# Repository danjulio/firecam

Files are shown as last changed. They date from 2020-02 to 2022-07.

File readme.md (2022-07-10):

## FireCAM - Timelapse thermal imaging camera

FireCAM is a timelapse camera designed to take both visual and radiometric thermal images periodically and record them as json-structured files to a local Micro-SD Card.  The visual images are stored in jpeg format.  The thermal images are the raw radiometric data (temperature) to enable later analysis.  The camera includes a touch LCD control panel and a WiFi interface allowing control, configuration and grabbing of images from an external application.

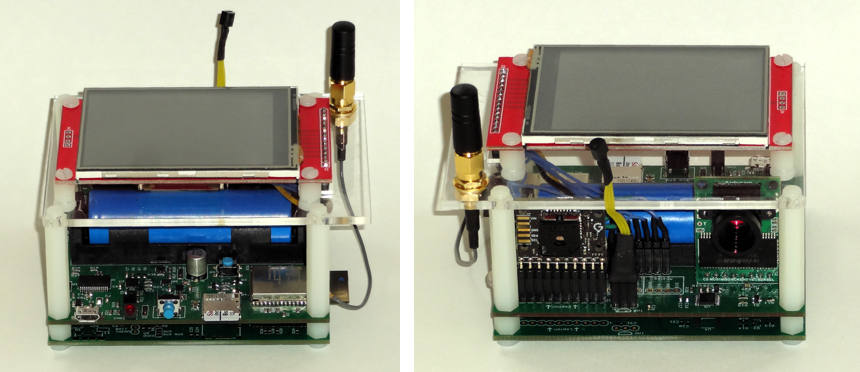
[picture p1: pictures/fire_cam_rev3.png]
FireCAM Rev 3 Hardware


### Features
* 160 x 120 pixel Radiometric Thermal Imaging Camera.
* 640 x 480 pixel Visual Imaging Camera.
* 2.8" 320 x 240 pixel Touchscreen for local control and configuration.
* Temperature sensor for external Thermal Imaging lens temp measurements.
* Micro-SD Card for image storage.
* Configurable timelapse times from 1 second to 1 hour per image.
* USB interface for charging, firmware updates and diagnostic output.
* 2500 mA LiPo battery with built-in charger can provide up to 5-6 hours of run-time and automatic low-battery shutdown.  Charger includes battery temperature monitor for charge limiting in extreme conditions.
* Wifi - AP or Client modes - for remote access.
* Battery-backed RTC for time and parameter storage.

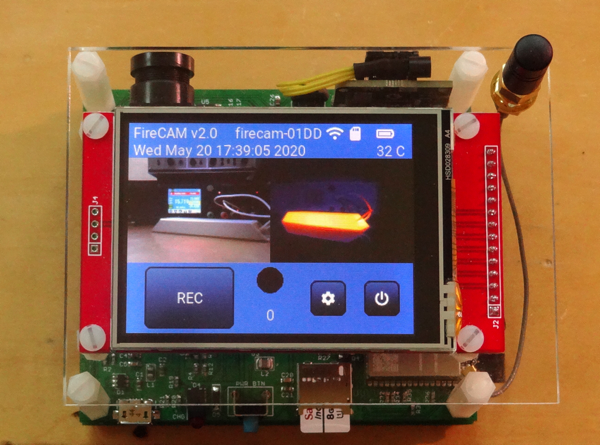
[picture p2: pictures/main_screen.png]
FireCAM Touchscreen Interface


### Origin
FireCAM was designed for the Joe O'Brien at [U.S. Forest Service Southern Research Station](https://www.srs.fs.usda.gov/).  It is released as Open Source software and hardware under the GPLv3 license.  The hardware design, firmware and a simple control application are contained in this repository.

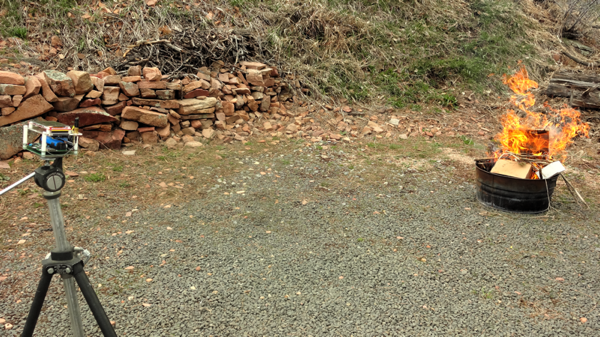
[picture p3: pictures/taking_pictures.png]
FireCAM in action


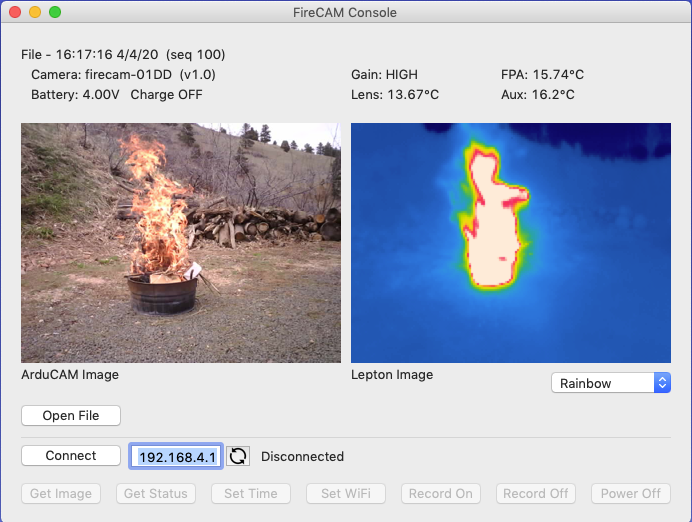
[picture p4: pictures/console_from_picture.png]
FireCAM Application


### Block Diagram
FireCAM 's image system is based around a FLiR Lepton 3.5 thermal imaging module and an ArduCAM visual sensor.  It uses an Espressif ESP32 micro-controller.  Firmware is written in C using the Esspressif v3.3.2 IDF and the LittlevGL v6.1.1 GUI library.  The desktop application is written using the Xojo cross-platform development tool.

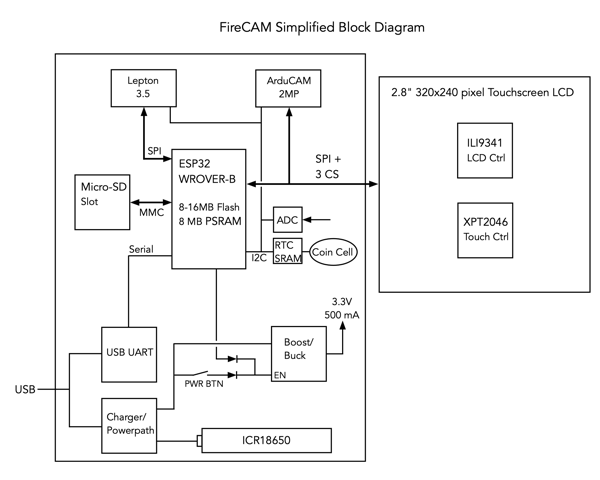
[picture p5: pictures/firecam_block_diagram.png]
FireCAM Block Diagram


### Version
This repository currently contains:

* Hardware Design Version: 3
* Firmware Revision: 2.1
* FireCAM Application Revision: 2.0

#### FW Revsion 2.1 Notes

1. Compile with QIO Flash access enabled (faster flash access).
2. Added Lepton state check (and refresh) before each acquisition.
3. Fixed minor bug in lepton init code (no functional impact).
4. Increased GUI task execution to every 50 mSec (was 100 mSec).
5. Additional performance debugging capabilty (disabled by default).

### Digital Object Identifier


### Questions
FireCAM was designed by Dan Julio (dan@danjuliodesigns.com).  Units may be available for purchase for qualified customers.  Customizations of the hardware, firmware or application are possible.

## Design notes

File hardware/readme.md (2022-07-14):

## FireCAM Hardware
This directory contains hardware design files.  Schematic entry and PCB layout was done using Eagle 7.7.

* display_mount - DXF and SVG files for a laser cut plastic display mount, OpenSCAD and STL files for a 3-piece 3D printed base and display mount.
* documentation - BOM, schematic, PCB image and helpful list of componentst to load on the PCB.
* eagle - Schematic and PCB Layout design files.
* gerber - PCB gerber files
* stencil - Stencil gerber files

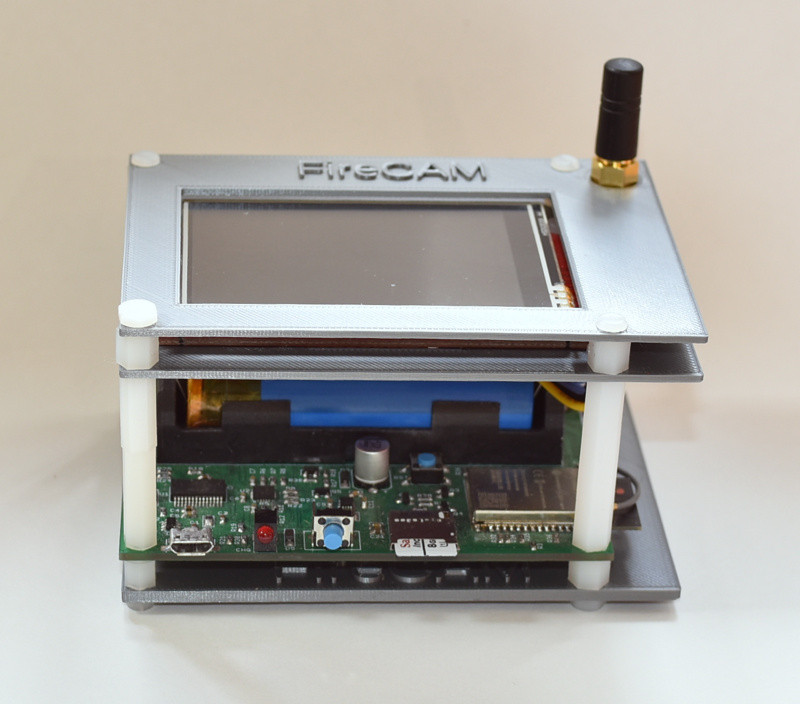
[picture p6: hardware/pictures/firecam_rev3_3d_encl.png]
FireCAM unit 3D enclosure

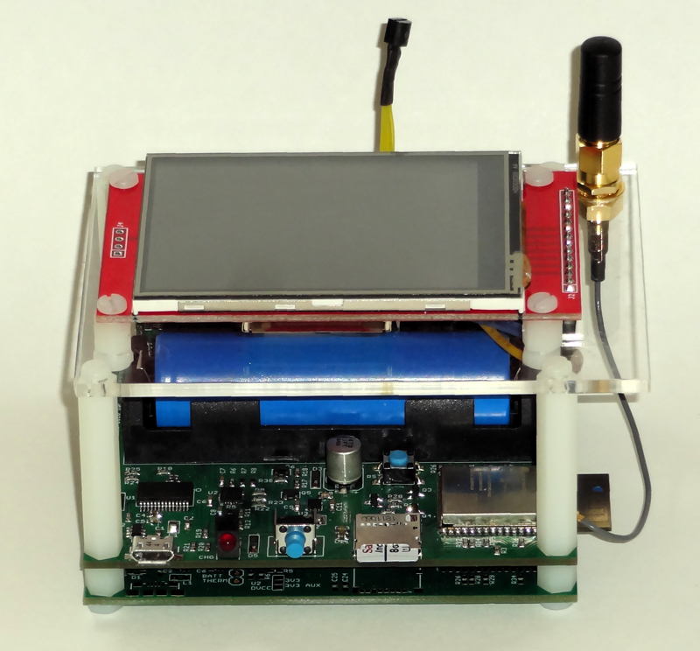
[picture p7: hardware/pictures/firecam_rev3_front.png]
FireCAM unit front


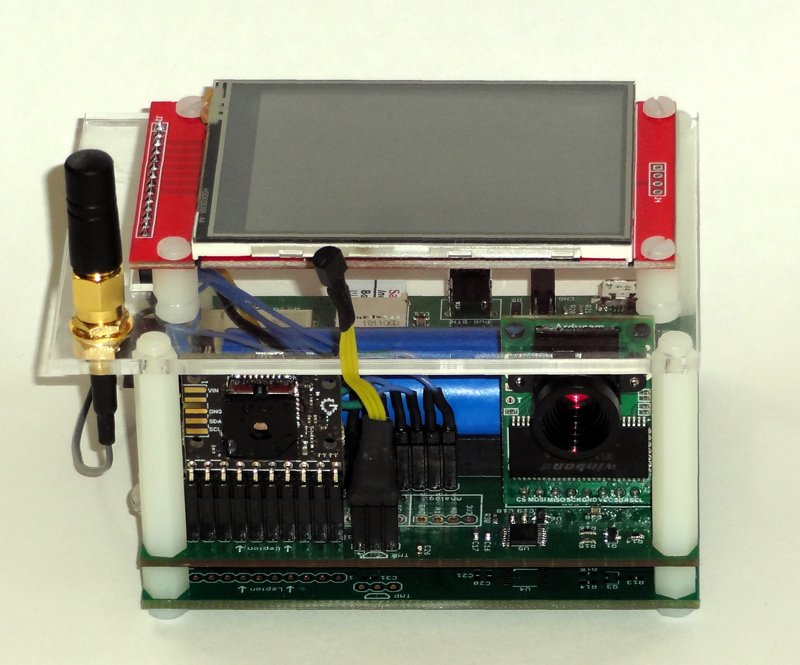
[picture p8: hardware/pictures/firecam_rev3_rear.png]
FireCAM unit rear


### Parts
Two shared Mouser BOMs are available for most of the components.

1. [FireCAM Rev 3 PCB Parts](https://www.mouser.com/ProjectManager/ProjectDetail.aspx?AccessID=e3b4e6fe5d) - Parts for direct mounting on the PCB.
2. [FireCAM Rev 3 Assembly Parts](https://www.mouser.com/ProjectManager/ProjectDetail.aspx?AccessID=ba0938d0f0) - Additional assembly parts.

In addition a commonly available 2.8" ILI9341/XPT2046 LCD display is used.  I have successfully sourced many units from the [HiLetGo](https://www.amazon.com/HiLetgo-240X320-Resolution-Display-ILI9341/dp/B073R7BH1B) store on Amazon but they are available from many sources.  You will also need some flexible 28 AWG silicon hook-up wire and heat shrink to make the Temperature Sensor and LCD wiring harnesses and a Micro-SD Card.

### Main PCB
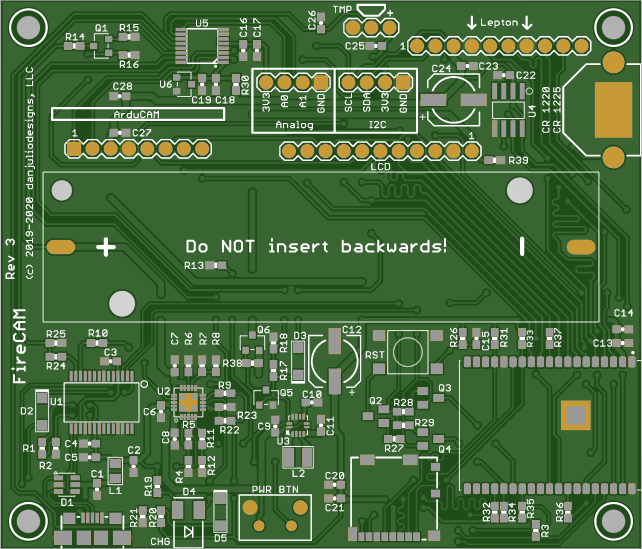
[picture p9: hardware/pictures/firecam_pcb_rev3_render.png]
FireCAM Rev 3 PCB Image


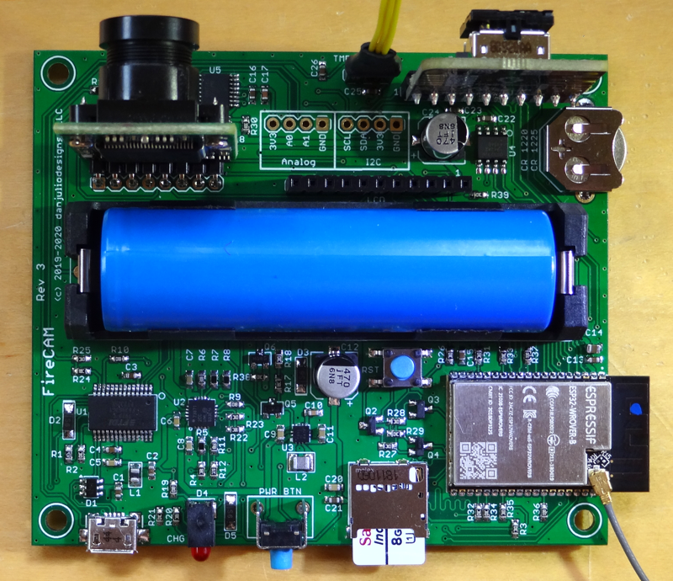
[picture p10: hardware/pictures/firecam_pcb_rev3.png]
FireCAM Rev 3 PCB


### Subassemblies

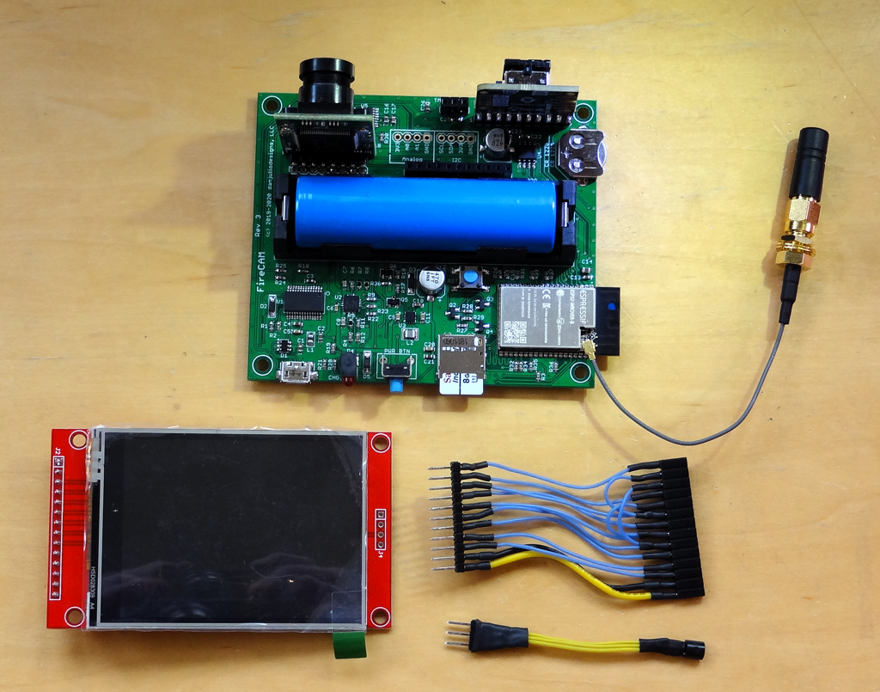
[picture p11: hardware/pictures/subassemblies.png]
FireCAM Subassemblies


#### Temperature probe
The TMP36 temperature sensor is connected to a 3-pin male 0.1" (2.54mm) using 3 2" (51 mm) 28 AWG wires.  Heatshrink each individual connection and the wire assembly to each of the connector and temperature sensor.  Note the orientation of the sensor relative to the connections on the PCB.

#### Display wiring harness
The Display harness contains the shared SPI bus for the LCD and Touchscreen, control, and power signals.  The shared SPI bus signals are connected at the display side in order to minimize signal reflections.
 
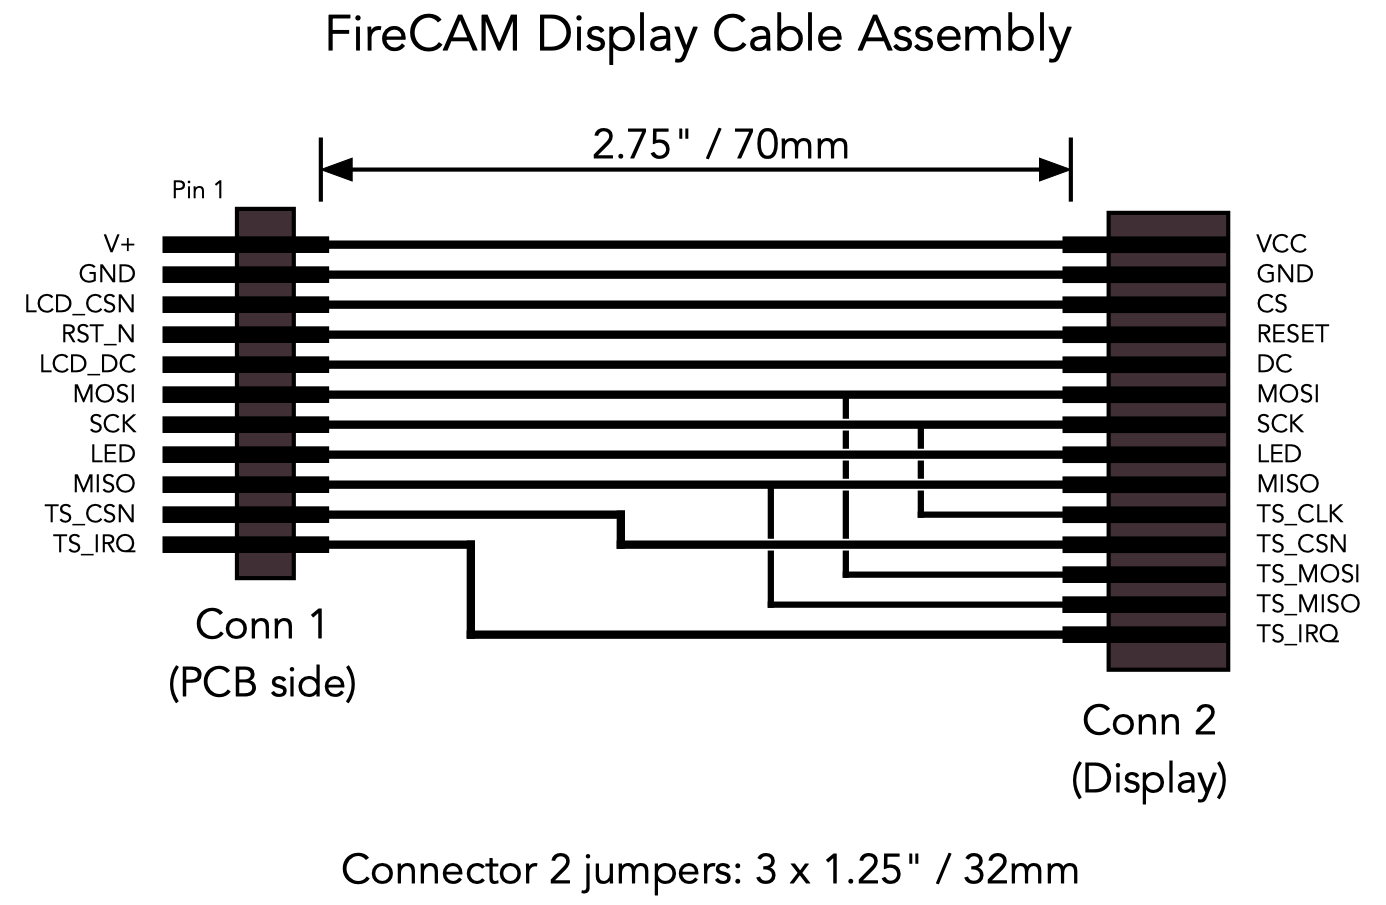
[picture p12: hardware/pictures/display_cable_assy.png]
FireCAM Display Wiring Harness


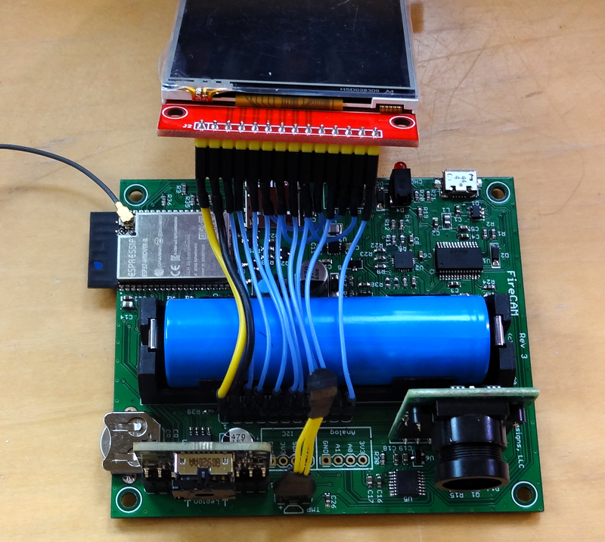
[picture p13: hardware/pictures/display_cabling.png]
FireCAM Wiring Harness Detail


#### 3D Printed Base and Display Mount
A base and two-piece display mount may be printed by slicing the STL files for your particular printer.  The STL was generated using OpenSCAD and the source files included here.

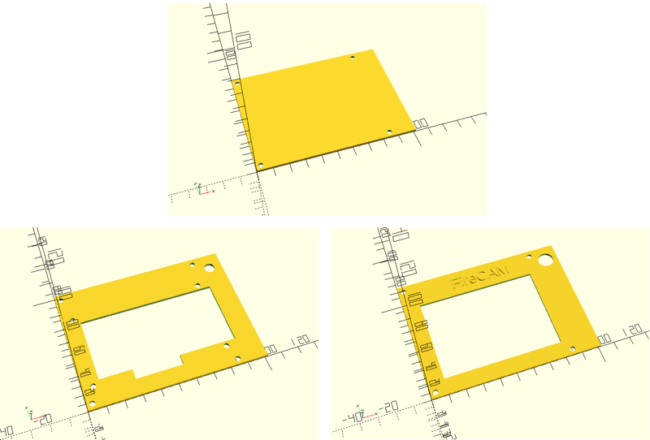
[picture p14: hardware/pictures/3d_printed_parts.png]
FireCAM 3D Printed Mount


#### Laser Cut Display Mount
The display mount is designed to be cut from a piece of 1/8" plastic on a laser cutter.

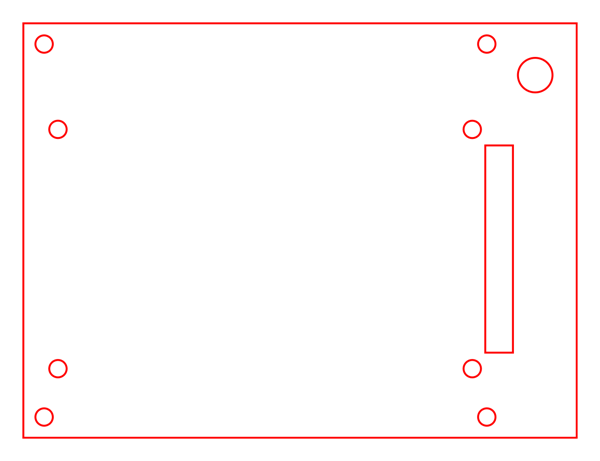
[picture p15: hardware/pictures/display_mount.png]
FireCAM Display Mount


### Enclosure
FireCAM is released without an enclosure as the original client for the project built their own custom enclosure for it.

### Expansion Ports

1. I2C Bus
2. ADC inputs A0 and A1 (not currently used by the firmware)

### Important Notes

1. Do not insert the LiPo battery backwards!  This will damage the camera electronics.
2. The RTC has a higher-than normal draw from the coin cell until it has been initialized.  Load firmware before inserting the coin cell and then immediately power on the camera to initialize the RTC (even if it has the wrong time).
3. Do not enable WiFi unless the antenna is connected.  It is possible to damage the ESP32 without an antenna.
4. The camera is charged from the USB port.  It will take a maximum of 500 mA from this port if it detects a charger attached (D+ connected to D-) or the USB port has been enumerated by an attached computer.  It will take a maximum of 100 mA from this port when attached to a computer but not enumerated.  It will suspect power draw when the USB bus is suspended (e.g. computer is put to sleep).  Current is shared between charging the battery and power the camera so the battery will charge faster if the camera is powered off.  The red LED lights while charging.  It will not charge if D+/D- are not connected together or connected to a computer USB port.  Most USB chargers will work.

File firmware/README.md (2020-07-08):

## FireCAM Firmware
This directory contains the firmware source files, build support and pre-compiled binary files ready for programming into hardware using EspressIF tools.

Firmware is written in C using the EspressIF v3.3.2 IDF (which must be installed on your computer) and the LittlevGL v6.1.1 GUI library (included here).  The firwmare consists of several concurrently operating FreeRTOS tasks that communicate using notifications, shared buffers and mutex protected data structures.

* components - Support libraries and modules.
* main - Primary task modules.
* precompiled - Contains the pre-compiled binary files copied from the build directory (not included here).
* sdkconfig - IDF build configuration.  You will have to run this, at least, to set the USB Serial device for your camera.
* version.txt - Firmware version source file.

The EspressIF IDF documentation, including instructions for installing and building, can be found [here](https://docs.espressif.com/projects/esp-idf/en/v3.3.2/index.html).

### Local Control
Pressing the power button applies power to the camera.  It must be held until the firmware boots and sets a hold signal to keep power applied until it is ready to poweroff the camera (from a user action, remote command or low-battery condition).  This requries about 2-3 seconds.  The LCD backlight is switched on when the hold signal is asserted.

#### Main Screen

The camera's touch controls are fairly intuitive.  Functionality is split into several screens. The main screen is displayed after the camera boots. It displays an image updated once per second from both cameras, provides status information and controls to start/stop recording, enter the settings screens and power-off the camera.  The camera may also be powered off by pressing and holding the power button for more than two seconds.  A power-off screen is displayed when the camera powers down.

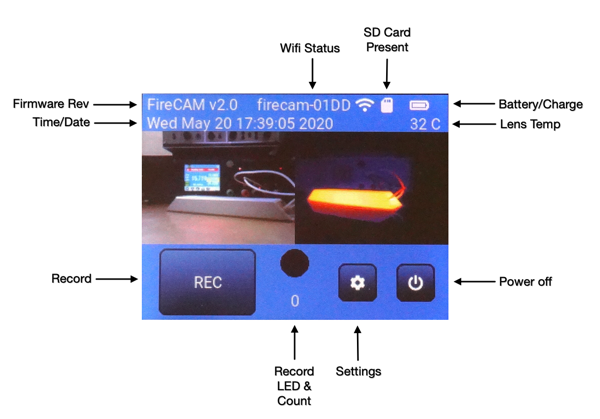
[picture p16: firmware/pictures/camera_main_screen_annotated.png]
Main Screen


* Battery/Charge - An estimate of the battery capacity is shown in the battery icon (0, 25, 50, 75, 100%) and a charge icon appears while the camera is charging the battery from the USB port.
* Firmware Rev - revision as contained in the version.txt file.
* Lens Temp - Temperature of the external TMP36 sensor.
* Power Button - Immediately powers down the camera.
* Record Button - Starts and stops recording.
* Record LED and Count - A simulated red LED is lit while recording and the number of images recorded during this session is displayed below it.
* SD Card Present - An icon shows when a Micro-SD Card has been inserted into the camera and recording can be started.  A pop-up messagebox is displayed if recording is attempted without an installed card.
* Settings Button - Displays the camera main settings screen.
* Time/Date - Displays the current time and date maintained by the camera.  This information is used to construct a unique directory for each recording session.
* WiFi Status - The current selected SSID is displayed.  When the camera is configured as an Access Point this is also the camera name.  A WiFi icon is displayed when the WiFi is active.

By default each camera is named ```firecam-HHHH``` where the 4-character hex string `HHHH` are from the ESP32's unique SoftAP Mac address.

#### Main Settings Screen

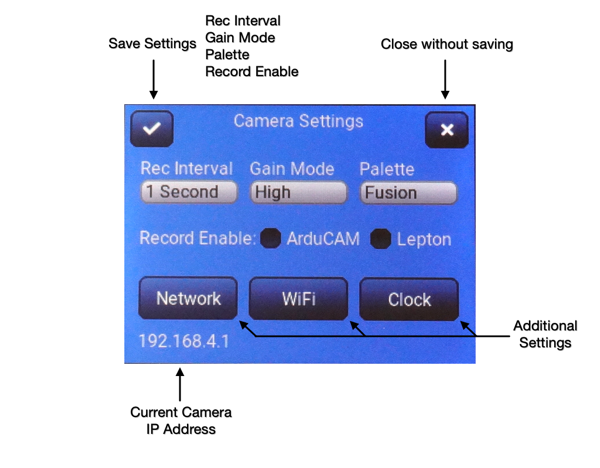
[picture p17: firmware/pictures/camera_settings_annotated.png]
Settings Screen


The main settings screen allows configuration of camera operating parameters.  The parameters, along with the time, are maintained by the battery-backed RTC chip when the camera is powered down.

* Additional Settings Buttons - These open additional settings screens.
* Close Without Saving Button - Returns to the main screen and discards any changes made to the Recording Interval, Gain Mode, Palette or Record Enable.
* Current Camera IP Address - Displays the Camera's IP address when it is acting as an Access Point.  Displays the Camera's IP address (either DHCP or static) when it is a client and connected to another Access Point.
* Save Settings - Save the values displayed for the Recording Interval, Gain Mode, Palette and Record Enable.

Camera Parameters modifed by this screen include the following.

* Rec Interval - Configures the time between recorded images when the camera is recording.   These values range from 1 second to 1 hour.
* Gain Mode - Configure the Lepton Gain Mode (please refer to the Lepton documentation for a detailed descripton of Gain Mode).
* Palette - Configures the false color palette used to display images from the Lepton on the main screen.
* Record Enable - Allows control of what camera images are saved during recording.  This may be useful, for example, to disable the ArduCAM when taking timelapse images at night.  One or both cameras must be selected.

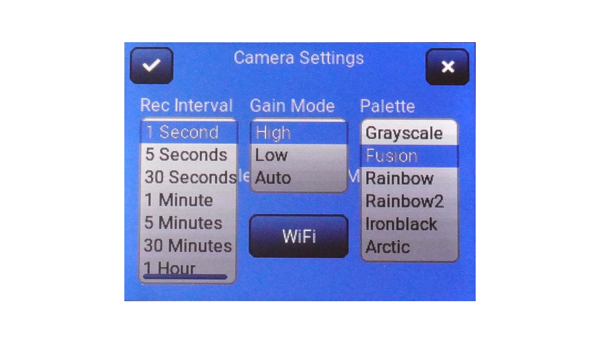
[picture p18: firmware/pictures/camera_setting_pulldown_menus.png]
Setting Screen Selections


#### Clock Settings Screen

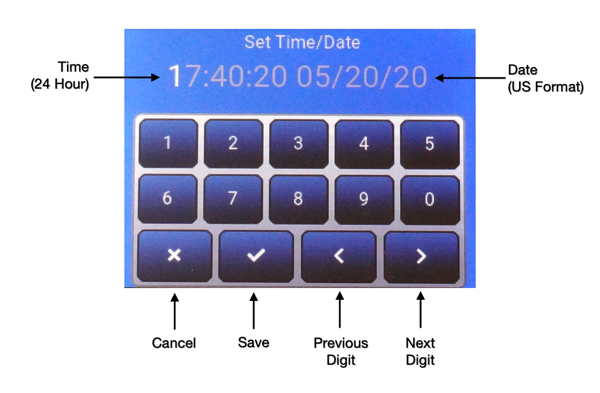
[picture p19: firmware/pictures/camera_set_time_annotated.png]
Clock Settings Screen


The Clock settings screen allows setting the camera's time and date. The time and date are set by entering them from left to right using the numeric keypad.  The currently selected digit is highlighted and automatically moves to the next digit as numbers are entered.  The screen will not allow setting illegal times or dates.

* Cancel Button - Returns to the main settings screen without changing the time and date.
* Next Digit Button - skips ahead to the next digit.
* Previous Digit Button - backs up one digit.
* Save - Saves the currently displayed time and date to the camera and RTC chip then returns to the main settings screen.

#### Wifi Settings Screen

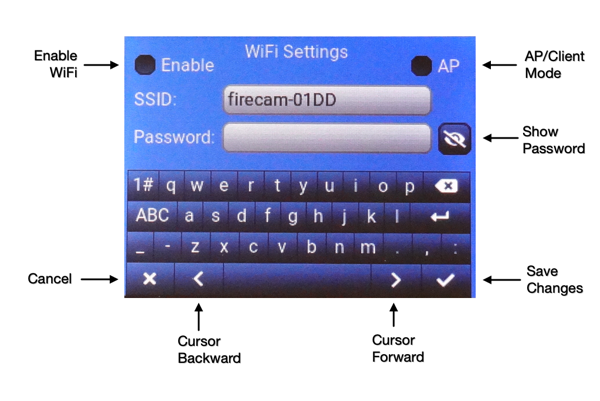
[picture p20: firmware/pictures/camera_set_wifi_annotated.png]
WiFi Settings Screen


The Wifi settings screen allows enabling or disabling WiFi, configuring the camera as an Access Point or client, and setting the camera's SSID and WPA password.  Note that it may be easier to use a stylus on the camera's resistive touch screen for entering information on this screen.

* AP/Client Mode Checkbox - Selecting this checkbox configures the camera as an Access Point that can support one client via DHCP.  De-selecting this checkbox configures the camera as a client that will attempt to connect to an Access Point.
* Cancel - Returns to the main settings screen without changing the WiFi configuration.
* Cursor Backward Button - Moves the cursor left one character position in the selected text box.
* Cursor Forward Button - Moves the cursor right one character position in the selected text box.
* Enable WiFi Checkbox - Selecting this checkbox enables the camera's WiFi interface.  De-selecting this checkbox disables the camera's WiFi interface.
* Password Text Box - Click in this to select it and enter up to a 32-character password.  When the camera is configured as an Access Point this is the password the connecting computer will use.  When the camera is configured as a client this is the password the camera will use.
* Save Changes Button - Saves the displayed WiFi configuration and returns to the main settings screen.  Restarts the WiFi as necessary with the new configuration.
* Show Password Button - Toggles showing or hiding the contents of the Password text box.
* SSID Text Box - Click in this to select it and enter up to a 32-character SSID.  When the camera is configured as an Access Point this is the SSID the camera will broadcast for the connecting computer to use.  When the camera is configured as a client this is the SSID the camera will attempt to connect with.

#### Network Settings Screen

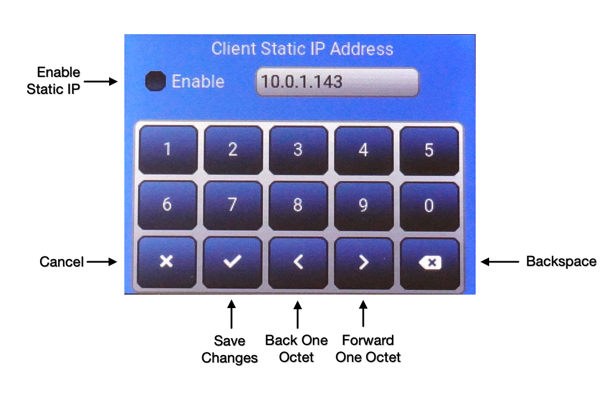
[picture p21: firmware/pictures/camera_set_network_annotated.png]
Network Settings Screen


The Network settings screen allows selecting between DHCP and Static IP addresses when the camera is configured as a client to another Access Point, and setting the static IP address.  A netmask of ```255.255.255.0``` is assumed by this version of the firmware.  The camera's current static IP address is displayed with a cursor at the end of the final octet.  Changes are made using the numeric keypad.  The screen will not allow creation of an illegal IP address.

* Backspace Button - Deletes the character immediately preceeding the cursor.  Sets the octet to 0 if the all characters in the octet are deleted.
* Back One Octet Button - Moves the cursor past the end character of the preceeding Octet value.
* Cancel Button - Returns to the main settings screen without changing the Network configuration.
* Enable Static IP Checkbox - Selecting this checkbox enables the camera to use a Static IP address.  De-selecting this checkbox enables the camera to request an address using DHCP.
* Forward One Octet Button - Moves the cursor past the end character of the subsequent Octet value.
* Save Changes Button - Saves the displayed Network configuration and returns to the main settings screen.  Restarts the WiFi as necessary with the new configuration.

### Recording Files
Recorded images are saved as json-structured files with several objects.  Each file is typically 70-100 kBytes in length.

* Metadata - Information about the camera and its environment.
* Visual Image - The variable length jpg image from the ArduCAM is formatted using Base-64.
* Lepton Radiometric Image - The 38,400 byte 16-bit per pixel radiometric (temperature) data from the Lepton is formatted using Base-64.
* Lepton Telemetry Data - The 480 byte 16-bit per word telemetry package containing information about the camera at the time the image was recorded is formatted using Base-64.

#### Missing Json objects
Occasionally one or both of the camera's may fail to generate an image.  The ArduCAM occasionally fails to generate a legal jpeg images (reason unknown).  The Lepton will not generate images while it is performing a flat-field correction.  If either or both of these occurs then the related object is not included in the file.

#### Recording Directory Layout
Files from one recording session are stored in two-level directory structure at the root of the Micro-SD card.  The top-level directory name is created from the current date and time.

```session_YY_MM_DD_HH_MM_SS```

Files are grouped in sets of 100 files per sub-directory under that.  Each sub-directory is named with an incrementing number starting at 0.  This is to mitigate performance issues with the underlying FAT-FS library as it scans a directory looking for duplicate file names.

```group_NNNN```

Files are named with an incrementing number starting at 0.

```img_MMMMM.json```

#### File Format
A complete file is shown below.  Most of the Base-64 data is omitted for clarity.

```
{
  "metadata": {
    "Camera": "firecam-01DD",
    "Version": "2.0",
    "Sequence Number": 0,
    "Time": "21:18:39",
    "Date": "5/18/20",
    "Battery": 4.170127868652344,
    "Charge": "OFF",
    "FPA Temp": 34.769981384277344,
    "AUX Temp": 34.969993591308594,
    "Lens Temp": 35.67091751098633,
    "Lepton Gain Mode": "HIGH",
    "Lepton Resolution": "0.01"
  },
  "jpeg": "/9j/4AAQSkZJRgABAQEAAAAAAA..."
  "radiometric": "I3Ypdg12B3YPdgt2BXYRdgF2A3YFdgF2AXYNdv91+3ULdvd..."
  "telemetry": "DgCDMSkAMAgAABBhCIKyzJpkj..."
}
```
Temperature values are in °C.  The sequence number is the same as the incrementing number in the file's name.  Battery value is in volts.

The Lepton Resolution is used with the Radiometric data to compute the temperature of each pixel.  The data is encoded either as °K with a resolution of 0.01°K (27315 = 0°C) or a resolution of 0.1°K (2731 = 0°C).

Refer to the Lepton 3.5 documentation for more information and for the contents of the telemetry object.

### Remote Command Interface
The camera is capable of executing a set of commands and providing a set of responses when connected to a remote computer via the WiFi interface.  It can support one remote connection at a time.  Commands and responses are encoded as json-structured strings.  The command interface exists as a TCP/IP socket at port 5001.

Each json command or response is delimited by two characters.  A start delimitor (value 0x02) preceeds the json string.  A end delimitor (value 0x03) follows the json string.  The json string may be tightly packed or may contain white space.  However no command may exceed 256 bytes in length.

```<0x02><json string><0x03>```

The camera currently supports the following commands.  The communicating application should wait for a response from commands that generate one before issuing subsequent commands (although the camera does have some buffering - 1024 bytes - for multiple commands).

* get_status - Returns an object with camera status.  The application uses this to verify communication with the camera.
* get_image - Returns an object, structured identically as the image file, with metadata, jpeg, radiometric and telemetry objects.  This command should be issued no more frequently than once per second and the application should wait for a response before issuing it again.
* set_time - Set the camera's clock and RTC.  Does not return anything.
* get_config - Returns an object with the camera's current settings.
* set_config - Set the camera's settings.  Does not return anything.
* get_wifi - Returns an object with the camera's current WiFi and Network configuration.
* set_wifi - Set the camera's WiFi and Network configuration.  The WiFi subsystem is immediately restarted.  The application should immediately close its socket after sending this command.  Does not return anything.
* record_on - Start a recording session.
* record_off - End a recording session.
* poweroff - Power down the camera.

The camera currently generates the following responses.

* config - Response to get_config command.
* image - Response to get_image command.
* status - Response to get_status command.
* wifi - Response to get_wifi command.

Example commands and responses are shown below.

#### get_status

```{"cmd":"get_status"}```

#### get_status response
```
{
  "status": {
    "Camera": "firecam-01DD",
    "Version": "2.0",
    "Recording": 0,
    "Time": "21:23:26",
    "Date": "5/18/20",
    "Battery": 4.170127868652344,
    "Charge": "OFF"
  }
}
```
The Recording object is set to 1 when the camera is recording and 0 when it is not.

#### get_image

```{"cmd":"get_image"}```

#### get_image response
The get_image response contains the exact same content as a file.  The Sequence Number will always contain the number 0 unless the camera is recording.

```
{
  "metadata": {
    "Camera": "firecam-01DD",
    "Version": "2.0",
    "Sequence Number": 0,
    "Time": "21:18:39",
    "Date": "5/18/20",
    "Battery": 4.170127868652344,
    "Charge": "OFF",
    "FPA Temp": 34.769981384277344,
    "AUX Temp": 34.969993591308594,
    "Lens Temp": 35.67091751098633,
    "Lepton Gain Mode": "HIGH",
    "Lepton Resolution": "0.01"
  },
  "jpeg": "/9j/4AAQSkZJRgABAQEAAAAAAA..."
  "radiometric": "I3Ypdg12B3YPdgt2BXYRdgF2A3YFdgF2AXYNdv91+3ULdvd..."
  "telemetry": "DgCDMSkAMAgAABBhCIKyzJpkj..."
}
```

### set_time

```
{
  "cmd": "set_time",
  "args": {
    "sec": 14,
    "min": 10,
    "hour": 21,
    "dow": 2,
    "day": 18,
    "mon": 5,
    "year": 50
  }
}
```
All set_time args must be included.

* sec - Seconds 0-59
* min - Minutes 0-59
* hour - Hour 0-23
* dow - Day of Week starting with Sunday 1-7
* day - Day of Month 1-28 to 1-31 depending
* mon - Month 1-12
* year - Year offset from 1970

#### get_config

```{"cmd":"get_config"}```

#### get_config response

```
{
  "config": {
    "arducam_enable": 1,
    "lepton_enable": 1,
    "gain_mode": 0,
    "record_interval": 1
  }
}
```
* arducam\_enable - Set to 1 to when the ArduCAM is enabled for recording sessions, set to 0 when it is disabled.
* lepton\_enable - Set to 1 to when the Lepton is enabled for recording sessions, set to 0 when it is disabled.
* gain\_mode - Set to 0 when the Lepton is configured in High Gain mode, set to 1 when the Lepton is configured in Low Gain mode and set to 2 when the Lepton is configured to automatically select between gain modes.
* record\_interval - Tthe number of seconds between recorded images in record mode.

#### set_config

```
{
  "cmd": "set_config",
  "args": {
    "arducam_enable": 1,
    "lepton_enable": 1,
    "gain_mode": 0,
    "record_interval": 1
  }
}
```
Individual args values may be left out.  The camera will use the existing value.

* arducam\_enable - Set to 1 to enable the ArduCAM during recording sessions, set to 0 to disable it.  At least one of arducam\_enable and lepton\_enable should be set.
* lepton\_enable - Set to 1 to enable the Lepton during recording sessions, set to 0 to disable it. At least one of arducam\_enable and lepton\_enable should be set.
* gain\_mode - Set to 0 to configure the Lepton in High Gain mode, set to 1 to configure the Lepton in Low Gain mode and set to 2 to configure the Lepton to automatically select between gain modes.
* record\_interval - Set the number of seconds between recorded images in record mode.  Note that this should match the firmware's existing values which are currently 1, 5, 30, 60, 300, 1800 or 3600.

#### get_wifi

```{"cmd":"get_wifi"}```

#### get_wifi response

```
{
  "wifi": {
    "ap_ssid": "firecam-01DD",
    "sta_ssid": "RoboNet",
    "flags": 159,
    "ap_ip_addr": "192.168.4.1",
    "sta_ip_addr": "10.0.1.144",
    "cur_ip_addr": "10.0.1.144"
  }
}
```
* ap_ssid - The camera's current AP-mode SSID and also the camera name as reported in the metadata and status objects.
* sta_ssid - The SSID used when the camera's WiFi is configured as a client.
* flags - 8-bit WiFi Status
	* 	Bit 7: Client Mode - Set to 1 for Client Mode, 0 for AP mode.
	* 	Bit 4: Static IP - Set to 1 to use a Static IP, 0 to request an IP via DHCP.
	* 	Bit 3: Wifi Connected - Set to 1 when connected to another device.
	* 	Bit 2: Wifi Client Running - Set to 1 when the client has been started, 0 when disabled (obviously this bit will never be 0).
	* 	Bit 1: Wifi Initialized - Set to 1 when the WiFi subsystem has been successfully initialized (obviously this bit will never be 0).
	* 	Bit 0: Wifi Enabled - Set to 1 to enable Wifi, 0 to disable Wifi.
* ap\_ip_addr - The camera's IP address when it is in AP mode (currently it will always be 192.168.4.1).
* sta\_ip_addr - The static IP address to use when the camera is in Client mode and configured to use a static IP.
* cur\_ip_addr - The camera's current IP address.  This may be a DHCP served address if the camera is configured in Client mode with static IP addresses disabled.

#### set_wifi
```
{
  "cmd": "set_wifi",
  "args": {
    "ap_ssid": "FireCam-3"
    "ap_pw: "apassword"
    "ap_ip_addr": "192.168.4.1",
    "flags": 145,
    "sta_ssid": "RoboNet",
    "sta_pw": "anotherpassword",
    "sta_ip_addr": "10.0.1.144"
  }
}
```
Individual args values may be left out (for example to just set AP or Client (sta) values.  The camera will use the existing value.

Only a subset of the flags argument are used.  Other bit positions are ignored.

* Bit 7: Client Mode - Set to 1 for Client Mode, 0 for AP mode.
* Bit 4: Static IP - Set to 1 to use a Static IP, 0 to request an IP via DHCP.
* Bit 0: Wifi Enabled - Set to 1 to enable Wifi, 0 to disable Wifi.

#### record_on

```{"cmd":"record_on"}```

#### record_off

```{"cmd":"record_off"}```

#### poweroff

```{"cmd":"poweroff"}```

### Special Notes
1. Recording resumes automatically if the firmware crashes.
2. Press and hold the power button when loading new firmware to keep the camera powered during the process (the hold signal from the ESP32 will be de-asserted when the ESP32 is reset before reprogramming).

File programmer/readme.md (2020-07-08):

## FireCAM Firmware Upload
There are two ways to load firmware into FireCAM.

1. Using the Espressif build process after compiling the firmware.
2. Using a download tool from Espressif to load the pre-compiled firmware from this repository.

The second option is described here.  It requires a Microsoft Windows computer.

### Download firmware files
Download the three binary files from this repository to a known location.  All three are required by the Espressif download tool.

```
	firmware/precompiled/bootloader.bin
	firmware/precompiled/firecam.bin
	firmware/precompiled/partitions_singleapp.bin
```

### Connect Camera
Connect the camera to the Windows Computer to allow it to load a device driver for the camera's FTDI USB-Serial chip.  The camera does not need to be powered on.  After a few minutes the computer should load a driver and associate a COM port with the camera.  Make a note of this port.  You can find it in the Windows Device Manager.

### Install the Espressif download tool
Download the `flash_download_tools_v3.6.8.zip` file to a Windows computer.  Unzip it in a known location.  It will unzip a directory named `flash_download_tools_v3.6.8`.  Execute the ```flash_download_tools_v3.6.8``` binary from within that directory.

A shell window will appear and then after a few seconds a selection window will appear.

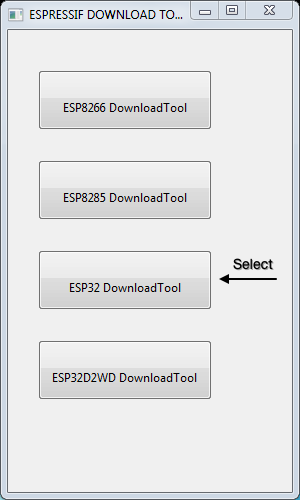
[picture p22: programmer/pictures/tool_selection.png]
Espressif Tool Selection


Click the `ESP32 Download Tool` button.  The ESP32 Download Tool program runs and displays a new window.

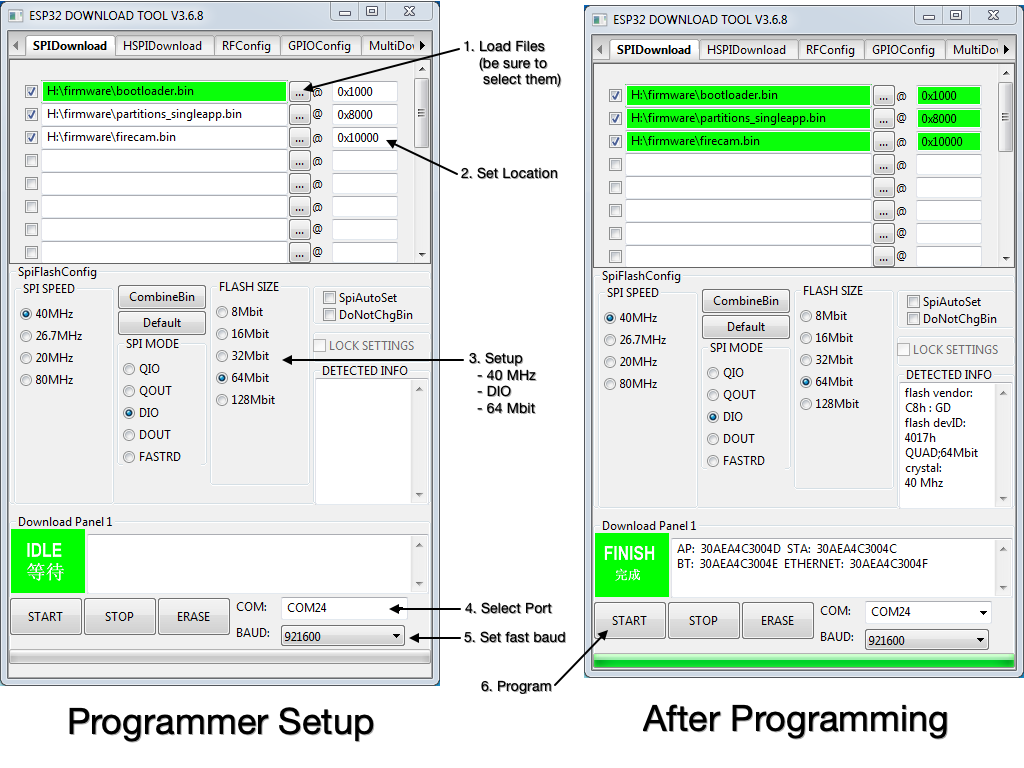
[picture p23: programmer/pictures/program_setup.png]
Espressif ESP32 Download Tool


#### Programmer Setup

1. Load the three firmware files from the location you stored them by clicking on first three `...` buttons as shown above under the `SPIDownload` tab.
2. Set the location in ESP32 memory for each file as shown above by clicking in the text fields to the right of each filename.
3. Configure the programming parameters in the `SpiFlashConfig` area.  Select SPI SPEED: 40 MHz, SPI MODE: DIO, FLASH SIZE: 64 Mbit.
4. Select the COM port associated with the camera.
5. Set a fast baud rate of 921600 baud to reduce programming time.

#### Programming

1. Press and hold the power button on the camera.  It will boot up but this does not matter (the programming software will reset it).
2. Continue to hold the power button depressed and press `START` to initiate programming.  A green progress bar will progress along the bottom of the window.  Programming should take 15-20 seconds.  The program will display `FINISH` upon a successful programming.
3. Release the power button and then press it again.  The camera should boot into the new firmware.

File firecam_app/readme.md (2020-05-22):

## FireCAM Application Program
This directory contains the FireCAM application program, compiled as 64-bit binaries for Windows and OS X platforms and its source code written for the Xojo development environment.

The Application program provides two functions.

1. Remote Camera Control - Get status and control the camera remotely including the ability to view live images from the camera.
2. Simple File Viewing - View files that have been copied from the camera's Micro-SD card to the computer.

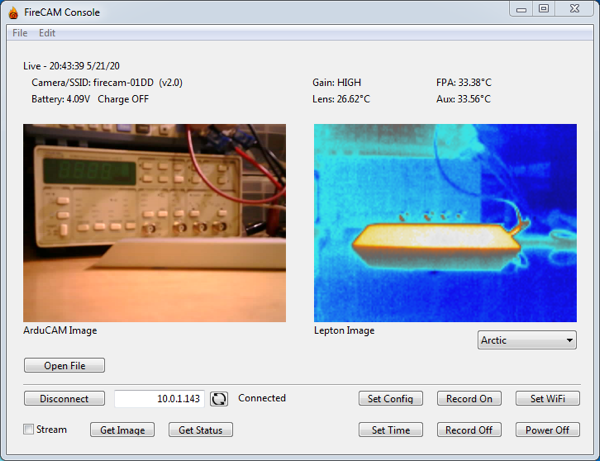
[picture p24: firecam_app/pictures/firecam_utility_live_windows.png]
Application Live on Windows


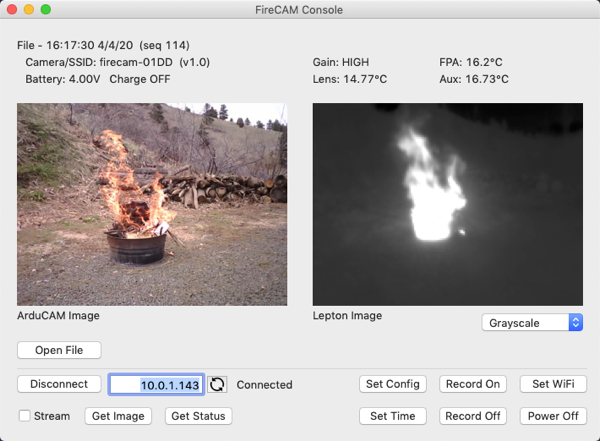
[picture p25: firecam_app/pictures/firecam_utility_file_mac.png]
Application File view on Mac


### Running the application
The pre-built binary files are found in the `Builds - firecam.xojo_binary_project`sub-directory.  For Windows, double-click the `firecam.exe` file.  For Mac, double-click the `firecam` application icon.

### File Display
The `Open File` button opens a file chooser pop-up allowing selection of a camera json file.  The status area above the images is updated from the file's metadata.

Note: A sample json image file is in the `pictures` sub-directory.

### Remote Camera Control
The computer the application is running on must be on the same network as the camera.  The application must be configured with the camera's IP address.

Application Network Controls

Clicking the refresh button to the right of the the IP text field will display the current address with the last octet set to '1'.  Clicking the `Connect` button will attempt to connect to the camera.  The camera's current status is displayed above the image area upon successful connection.

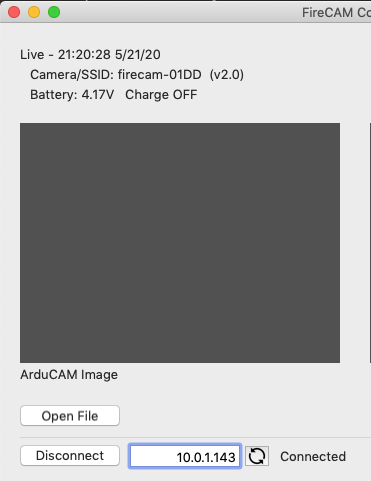
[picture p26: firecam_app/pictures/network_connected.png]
Application Connected


Once connected the camera controls are active.

* `Get Image` - Gets a pair of images from the camera and displays them along with metadata above the images.
* `Get Status` - Gets the camera status and displays it above the images.  The displayed status indicates if the camera is currently recording or not.
* `Poweroff` - Commands the camera to power down (a pop-up message box is displayed first for verification).
* `Record On` - Starts a recording session.  A Micro-SD card must be inserted or this button will have no effect.
* `Record Off` - Ends a recording session.
* `Set Config` - Queries the camera for its current camera settings and displays a settings window to make changes.  
* `Set Time` - Sets the camera time from the computer time.
* `Set WiFi` - Queries the camera for its current WiFi and network settings and displays a settings window to make changes.
* `Stream` - Clicking this checkbox causes the application to continuously request an image every second.  The application will not request a new image until the previous request has been fulfilled so this may result in slower than once/second updates.

#### Set Config

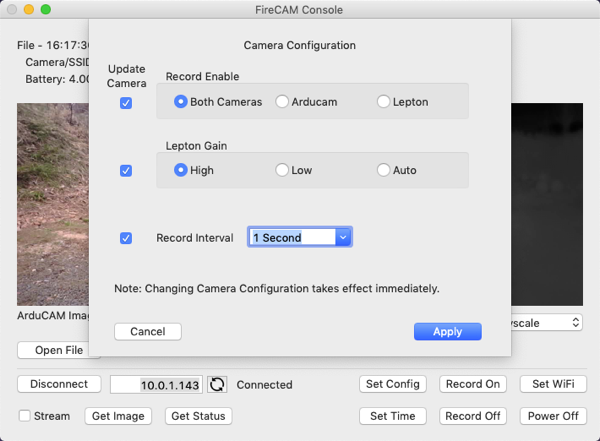
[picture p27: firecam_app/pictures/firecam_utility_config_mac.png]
Application Config Window


Only items with the associated `Update Camera` checkbox selected will be updated if Apply is pressed.

#### Set WiFi

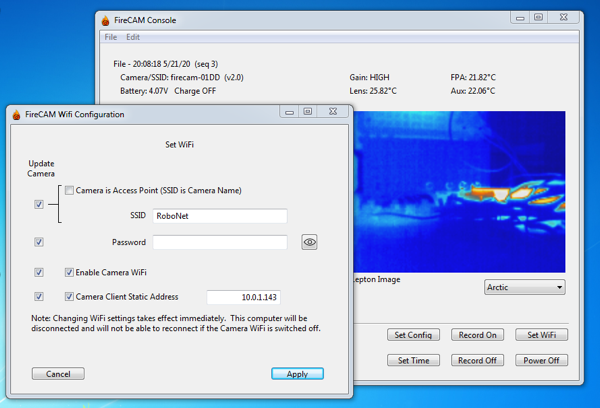
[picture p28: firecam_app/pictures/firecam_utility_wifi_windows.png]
Applicatoin WiFi Window


Only items with the associated `Update Camera` checkbox selected will be updated if `Apply` is pressed.  Changing the Camera is Access Point checkbox will reset the `SSID` text field with the current SSID for either AP or client mode.

Note: The `Password` text field from the camera is not populated with the camera's existing password.

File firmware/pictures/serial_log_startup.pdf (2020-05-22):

rst:0x1 (POWERON_RESET),boot:0x1f (SPI_FAST_FLASH_BOOT)
configsip: 0, SPIWP:0xee
clk_drv:0x00,q_drv:0x00,d_drv:0x00,cs0_drv:0x00,hd_drv:0x00,wp_drv:0x00 mode:DIO, clock div:2
load:0x3fff0018,len:4
load:0x3fff001c,len:6420
load:0x40078000,len:11624
load:0x40080400,len:6700
entry 0x40080768
I (28) boot: ESP-IDF v3.3-dirty 2nd stage bootloader I (29) boot: compile time 20:50:29
I (29) boot: Enabling RNG early entropy source...
I (33) boot: SPI Speed | : 40MHz
I (38) boot: SPI Mode | : DIO
I (42) boot: SPI Flash Size : 8MB
I (46) boot: Partition Table:
I (49) boot: ## Label | Usage | Type ST Offset | Length
I (57) boot: | 0 nvs | WiFi data | 01 02 00009000 00006000
I (64) boot: | 1 phy_init | RF data | 01 01 0000f000 00001000
I (71) boot: | 2 factory | factory app | 00 00 00010000 00100000
I (79) boot: End of partition table
I (83) esp_image: segment 0: paddr=0x00010020 vaddr=0x3f400020 size=0x38170 (229744) map
I (173) esp_image: segment 1: paddr=0x00048198 vaddr=0x3ffb0000 size=0x037c4 ( 14276) load
I (179) esp_image: segment 2: paddr=0x0004b964 vaddr=0x40080000 size=0x00400 ( 1024) load
0x40080000: _WindowOverflow4 at /Users/danjulio/esp/esp-idf/components/ freertos/xtensa_vectors.S:1779

I (180) esp_image: segment 3: paddr=0x0004bd6c vaddr=0x40080400 size=0x042a4 ( 17060) load
I (195) esp_image: segment 4: paddr=0x00050018 vaddr=0x400d0018 size=0xa5b74 (678772) map
0x400d0018: _stext at ??:?

I (435) esp_image: segment 5: paddr=0x000f5b94 vaddr=0x400846a4 size=0x14668 ( 83560) load
0x400846a4: psram_enable at /Users/danjulio/esp/esp-idf/components/esp32/ spiram_psram.c:707

I (485) boot: Loaded app from partition at offset 0x10000
I (485) boot: Disabling RNG early entropy source...
I (486) psram: This chip is ESP32-D0WD
I (491) spiram: Found 64MBit SPI RAM device
I (494) spiram: SPI RAM mode: flash 40m sram 40m
I (500) spiram: PSRAM initialized, cache is in low/high (2-core) mode. I (507) cpu_start: Pro cpu up.
I (511) cpu_start: Application information:
I (516) cpu_start: Project name: | firecam
I (520) cpu_start: App version: | 2.0
I (525) cpu_start: Compile time: | May 12 2020 20:50:28
I (531) cpu_start: ELF file SHA256: | 706d19a33463d4d4...
I (537) cpu_start: ESP-IDF: | v3.3-dirty

I (542) cpu_start: Starting app cpu, entry point is 0x400815e8 0x400815e8: call_start_cpu1 at /Users/danjulio/esp/esp-idf/components/ esp32/cpu_start.c:270

I (0) cpu_start: App cpu up.
I (554) heap_init: Initializing. RAM available for dynamic allocation: I (560) heap_init: At 3FFAE6E0 len 00001920 (6 KiB): DRAM
I (566) heap_init: At 3FFD49B8 len 0000B648 (45 KiB): DRAM
I (572) heap_init: At 3FFE0440 len 00003AE0 (14 KiB): D/IRAM
I (578) heap_init: At 3FFE4350 len 0001BCB0 (111 KiB): D/IRAM
I (585) heap_init: At 40098D0C len 000072F4 (28 KiB): IRAM
I (591) cpu_start: Pro cpu start user code
I (596) spiram: Adding pool of 4078K of external SPI memory to heap allocator
I (170) cpu_start: Chip Revision: 1
I (171) cpu_start: Starting scheduler on PRO CPU.
I (0) cpu_start: Starting scheduler on APP CPU.
I (174) spiram: Reserving pool of 32K of internal memory for DMA/internal allocations
I (184) main: FireCAM startup
I (184) sys: ESP32 Peripheral Initialization
I (1194) sys: System Peripheral Initialization
I (1194) time_utilities: Initial RTC time: Mon May 18 20:33:49 2020 I (1714) lepton_utilities: Lepton Radiometry = 1
I (1724) lepton_utilities: Lepton Radiometry TLinear = 1
I (1734) lepton_utilities: Lepton Radiometry Auto Resolution = 1 I (1744) lepton_utilities: Lepton AGC = 0
I (1754) lepton_utilities: Lepton Telemetry = 1
I (1764) lepton_utilities: Lepton Gain Mode = 0
I (1764) lepton_utilities: Lepton GPIO Mode = 5
I (1764) gpio: GPIO[13]| InputEn: 0| OutputEn: 1| OpenDrain: 0| Pullup: 0| Pulldown: 0| Intr:0
I (1824) wifi: wifi driver task: 3ffdcf70, prio:23, stack:3584, core=0
I (1824) system_api: Base MAC address is not set, read default base MAC address from BLK0 of EFUSE
I (1824) system_api: Base MAC address is not set, read default base MAC address from BLK0 of EFUSE
I (1854) wifi: wifi firmware version: aeed694
I (1854) wifi: config NVS flash: enabled
I (1854) wifi: config nano formating: disabled
I (1854) wifi: Init dynamic tx buffer num: 32
I (1864) wifi: Init data frame dynamic rx buffer num: 32
I (1864) wifi: Init management frame dynamic rx buffer num: 32 I (1874) wifi: Init management short buffer num: 32
I (1874) wifi: Init static tx buffer num: 16
I (1884) wifi: Init static rx buffer size: 1600
I (1884) wifi: Init static rx buffer num: 10
I (1884) wifi: Init dynamic rx buffer num: 32
I (1984) phy: phy_version: 4102, 2fa7a43, Jul 15 2019, 13:06:06, 0, 0 I (1984) wifi: mode : sta (30:ae:a4:c3:01:dc)
I (1984) wifi_utilities: WiFi Station starting
I (1984) wifi_utilities: Station started, trying to connect to RoboNet I (1994) sys: Buffer Allocation
I (2014) cam_task: Start task

I (2014) lep_task: Start task I (2014) cmd_task: Start task I (2014) gui_task: Start task I (2014) adc_task: Start task
I (2014) app_task: Start task
I (2014) file_task: Start task
I (2024) ili9341: ILI9341 initialization
I (2234) xpt2046: Touchpad initialization I (2244) palettes: Loading Arctic color map I (2314) file_task: SD Card found
I (2514) cmd_task: Socket created
I (2514) cmd_task: Socket bound
I (2514) cmd_task: Socket listening
I (3214) wifi: new:<11,0>, old:<1,0>, ap:<255,255>, sta:<11,0>, prof:1 I (3214) wifi: state: init -> auth (b0)
I (3214) wifi: state: auth -> assoc (0)
I (3224) wifi: state: assoc -> run (10)
I (3224) wifi: connected with RoboNet, channel 11, HT20, bssid = 74:44:01:d7:94:75
I (3224) wifi: pm start, type: 1

I (3234) event: sta ip: 10.0.1.144, mask: 255.255.255.0, gw: 0.0.0.0 I (3234) wifi_utilities: Connected. Got ip: 10.0.1.144

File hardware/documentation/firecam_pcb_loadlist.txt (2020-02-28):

PCB Load Partlist

Exported from firecam.sch at 2/12/20 12:23 PM

EAGLE Version 7.7.0 Copyright (c) 1988-2016 CadSoft

Assembly variant: Rev 3

Part     Value          Device               Package             Library             Sheet

A1       ESP32-WROVER-I ESP32-WROVER-I       XCVR_ESP32-WROVER-I ESP32-WROVER-I      3

BAT1                    18650_BATTERYTH      KEYSTONE_1043       djd_eagle_library   2
BAT2                    COIN_CELL12MM        KEYSTONE_3001       djd_eagle_library   3

C1       0.1 uF         C-USSMT0603          C0603               djd_eagle_library   1
C2       0.1 uF         C-USSMT0603          C0603               djd_eagle_library   1
C3       0.1 uF         C-USSMT0603          C0603               djd_eagle_library   1
C4       0.1 uF         C-USSMT0603          C0603               djd_eagle_library   1
C13      0.1 uF         C-USSMT0603          C0603               djd_eagle_library   3
C15      0.1 uF         C-USSMT0603          C0603               djd_eagle_library   3
C16      0.1 uF         C-USSMT0603          C0603               djd_eagle_library   3
C18      0.1 uF         C-USSMT0603          C0603               djd_eagle_library   3
C21      0.1 uF         C-USSMT0603          C0603               djd_eagle_library   3
C22      0.1 uF         C-USSMT0603          C0603               djd_eagle_library   3
C23      0.1 uF         C-USSMT0603          C0603               djd_eagle_library   4
C25      0.1 uF         C-USSMT0603          C0603               djd_eagle_library   4
C26      0.1 uF         C-USSMT0603          C0603               djd_eagle_library   4
C27      0.1 uF         C-USSMT0603          C0603               djd_eagle_library   4

C5       10 uF          C-USSMT0603          C0603               djd_eagle_library   1
C6       10 uF          C-USSMT0603          C0603               djd_eagle_library   2
C7       10 uF          C-USSMT0603          C0603               djd_eagle_library   2
C8       10 uF          C-USSMT0603          C0603               djd_eagle_library   2

C9       22 uF          C-USSMT0603          C0603               djd_eagle_library   2
C11      22 uF          C-USSMT0603          C0603               djd_eagle_library   2
C14      22 uF          C-USSMT0603          C0603               djd_eagle_library   3
C20      22 uF          C-USSMT0603          C0603               djd_eagle_library   3
C28      22 uF          C-USSMT0603          C0603               djd_eagle_library   4

C10      1 nF           C-USSMT0603          C0603               djd_eagle_library   2

C12      470 uF         CPOL-USSMT06X06      ECAP-0606           djd_eagle_library   2
C24      470 uF         CPOL-USSMT06X06      ECAP-0606           djd_eagle_library   4

C17      2.2 uF         C-USSMT0603          C0603               djd_eagle_library   3
C19      2.2 uF         C-USSMT0603          C0603               djd_eagle_library   3

CON1     47346-0001     USBMICROB            USB_MICROB_SMT      djd_eagle_library   1
CON2     104031-0811    MOLEX_1040310811     MOLEX_1040310811    djd_eagle_library   3

D1       USBLC6-25C6    USBLC6-2SOT23-6      SOT23-6             djd_eagle_library   1

D2       SD103          DIODESMT_SOD123      SOD123              djd_eagle_library   1
D3       SD103          DIODESMT_SOD123      SOD123              djd_eagle_library   2
D5       SD103          DIODESMT_SOD123      SOD123              djd_eagle_library   2

D4       RED            LEDLUMEX_SMT_3MM     LUMEX_3MM_SMT       djd_eagle_library   2

J1                      M10SILK_FEMALE_PTH   1X10                SparkFun-Connectors 4
J3                      M03PTH               1X03                SparkFun-Connectors 4
J4                      M11PTH               1X11                SparkFun-Connectors 4

L1       MI0805K400R-10 INDUCTORSMT0805      L0805               djd_eagle_library   1

L2       1.5 uH         INDUCTORSMT1008      L1008               djd_eagle_library   2

PB1                     PB_SMT_SIDEPTS645    PTS645_SIDE_TH      djd_eagle_library   2
PB2                     PB_TACT_4SMTR92      CK_PTS645_SMT       djd_eagle_library   3

Q1       NX7002AKVL     MOSFET-NCHANNELSOT23 SOT23-3             djd_eagle_library   2
Q5       NX7002AKVL     MOSFET-NCHANNELSOT23 SOT23-3             djd_eagle_library   4

Q2       MMBT3904-7-F   BC808-NPN-SOT23-BEC  SOT23-BEC           transistor          3
Q3       MMBT3904-7-F   BC808-NPN-SOT23-BEC  SOT23-BEC           transistor          3
Q4       MMBT3904-7-F   BC808-NPN-SOT23-BEC  SOT23-BEC           transistor          3

Q6       NX2301P,215    MOSFET-PCHANNEL      SOT23-3             djd_eagle_library   4

R1       4.7 kohm       R-USSMT0603          R0603               djd_eagle_library   1

R2       10 kohm        R-USSMT0603          R0603               djd_eagle_library   1
R3       10 kohm        R-USSMT0603          R0603               djd_eagle_library   1
R15      10 kohm        R-USSMT0603          R0603               djd_eagle_library   2
R18      10 kohm        R-USSMT0603          R0603               djd_eagle_library   2
R21      10 kohm        R-USSMT0603          R0603               djd_eagle_library   2
R23      10 kohm        R-USSMT0603          R0603               djd_eagle_library   2
R25      10 kohm        R-USSMT0603          R0603               djd_eagle_library   1
R26      10 kohm        R-USSMT0603          R0603               djd_eagle_library   3
R27      10 kohm        R-USSMT0603          R0603               djd_eagle_library   3
R28      10 kohm        R-USSMT0603          R0603               djd_eagle_library   3
R29      10 kohm        R-USSMT0603          R0603               djd_eagle_library   3
R31      10 kohm        R-USSMT0603          R0603               djd_eagle_library   3
R32      10 kohm        R-USSMT0603          R0603               djd_eagle_library   3
R33      10 kohm        R-USSMT0603          R0603               djd_eagle_library   3
R34      10 kohm        R-USSMT0603          R0603               djd_eagle_library   3
R35      10 kohm        R-USSMT0603          R0603               djd_eagle_library   3
R38      10 kohm        R-USSMT0603          R0603               djd_eagle_library   4
R39      10 kohm        R-USSMT0603          R0603               djd_eagle_library   4

R4       15 kohm        R-USSMT0603          R0603               djd_eagle_library   2
R17      15 kohm        R-USSMT0603          R0603               djd_eagle_library   2
R20      15 kohm        R-USSMT0603          R0603               djd_eagle_library   2
R22      15 kohm        R-USSMT0603          R0603               djd_eagle_library   2
R24      15 kohm        R-USSMT0603          R0603               djd_eagle_library   1

R5       40.2 kohm      R-USSMT0603          R0603               djd_eagle_library   2
R7       40.2 kohm      R-USSMT0603          R0603               djd_eagle_library   2
R8       40.2 kohm      R-USSMT0603          R0603               djd_eagle_library   2
R14      40.2 kohm      R-USSMT0603          R0603               djd_eagle_library   2
R16      40.2 kohm      R-USSMT0603          R0603               djd_eagle_library   2

R6       2 kohm         R-USSMT0603          R0603               djd_eagle_library   2
R30      2 kohm         R-USSMT0603          R0603               djd_eagle_library   3

R9       1 kohm         R-USSMT0603          R0603               djd_eagle_library   2
R10      1 kohm         R-USSMT0603          R0603               djd_eagle_library   2
R19      1 kohm         R-USSMT0603          R0603               djd_eagle_library   2

R11      1.54 kohm      R-USSMT0603          R0603               djd_eagle_library   2

R12      69.8 kohm      R-USSMT0603          R0603               djd_eagle_library   2

R13      MM103J1K       R-USSMT0603          R0603               djd_eagle_library   2

R36      33 ohm         R-USSMT0603          R0603               djd_eagle_library   3
R37      33 ohm         R-USSMT0603          R0603               djd_eagle_library   3

U1       FT232RL        FT232RLSSOP28        SSOP28DB            djd_eagle_library   1

U2       MCP73871       MCP73871             QFN20               adafruit            2

U3       TPS63051       TPS63051_QFN         HOTROD_QFN12        djd_eagle_library   2

U4       DS3232M        DS3232M              SO8                 djd_eagle_library   3

U5       ADC128D818     ADC128D818           SSOP16              djd_eagle_library   3

U6       LM4050AEM3-2.0 VOLTAGE_REFSMT_SOT23 SOT23-3             djd_eagle_library   3

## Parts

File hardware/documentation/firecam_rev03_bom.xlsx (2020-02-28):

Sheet: FireCAM - Rev 03 - PCB Assy
FireCAM PCB Assembly - Rev 03
Line No | Qty | Ref Desg | Part Number | Manuf | Package/Type | Desc | Distributor Part Number | Notes
1 | 1 | A1 | ESP32-WROVER-IB (8MB) | Esspressif | SMD/Module | WiFi Modules (802.11) SMD MODULE, 3.3V ESP32-DOWD, 8Mb Flash, EXT IPEX ANT; M213DH6464UC3Q0 | Mouser 356-ESP32-WROIB(8MB)
2 | 1 | BAT1 | 1043 | Keystone Electronics | TH | Cylindrical Battery Contacts, Clips, Holders & Springs 18650 PCB PLASTIC BATT HLDR THM 1 CELL | Mouser 534-1043
3 | 1 | BAT2 | 3001 | Keystone Electronics | TH | Coin Cell Battery Holders TH COIN CELL BATTERY HOLDER 12mm | Mouser 534-3001
4 | 14 | C1, C2, C3, C4, C13, C15, C16, C18, C21, C22, C23, C25, C26, C27 | EMK107B7104KAHT | Taiyo Yuden | SMD/0603 | Multilayer Ceramic Capacitors MLCC - SMD/SMT 0.1uF 16V X7R 10% 0603 | Mouser 963-EMK107B7104KAHT
5 | 4 | C5, C6, C7, C8 | GRM188R60J106KE47D | Murata | SMD/0603 | Multilayer Ceramic Capacitors MLCC - SMD/SMT 10UF 6.3V 10% 0603 | Mouser 81-GRM188R60J106KE7D
6 | 5 | C9, C11, C14, C20, C28 | GRM188R60J226MEA0D | Murata | SMD/0603 | Multilayer Ceramic Capacitors MLCC - SMD/SMT 0603 22uF 6.3volts | Mouser 81-GRM188R60J226ME0D
7 | 1 | C10 | C0603C102K3RACTU | Kemet | SMD/0603 | Multilayer Ceramic Capacitors MLCC - SMD/SMT 25V 1000pF 0603 X7R 10% | Mouser 80-C0603C102K3R
8 | 2 | C12, C24 | EEE-FTJ471XAP | Panasonic | SMD/6.3mm | Aluminum Electrolytic Capacitors - SMD 470uF 6.3volts 6.3x7.7mm SMD | Mouser 667-EEE-FTJ471XAP
9 | 2 | C17, C19 | C1608X7R0J225K080AB | TDK | SMD/0603 | Multilayer Ceramic Capacitors MLCC - SMD/SMT 0603 6.3V 2.2uF X7R 10% | Mouser 810-C1608X7R0J225K
10 | 1 | CON1 | 47346-0001 | Molex | SMD | USB Connectors MICRO USB B RECPT BTTM MOUNT ASSY | Mouser 538-47346-0001
11 | 1 | CON2 | 104031-0811 | Molex | SMD | Memory Card Connectors MICRO SD PUSH-PULL SMT 1.42MM HEIGHT | Mouse 538-104031-0811
12 | 1 | D1 | USBLC6-2SC6 | STMicroelectronics | SMD/SOT23-6 | ESD Suppressors / TVS Diodes ESD Protection Low Cap | Mouser 511-USBLC6-2SC6
13 | 3 | D2, D3, D4 | SD103CW RHG | Taiwan Semiconductor | SMD/SOD-123 | Schottky Diodes & Rectifiers SOD-123, 20V, 0.35A, Schottky Diode | Mouser 821-SD103CWRHG
14 | 1 | D4 | SSF-LXH305ID | Lumex | SMD | LED Circuit Board Indicators Rt Angle Block Red | Mouser 696-SSF-LXH305ID
15 | 1 | J1 | 801-83-010-10-003101 | Preci-dip | TH | 10 Position, 2.54mm, 1 Row, Straight Pin, Female Header | Mouser 437-8018301010003101
16 | 1 | J3 | 801-83-011-10-003101 | Preci-dip | TH | 11 Position, 2.54mm, 1 Row, Straight Pin, Female Header | Mouser 437-8018301110003101
17 | 1 | J4 | 801-83-003-10-003101 | Preci-dip | TH | 3 Position, 2.54mm, 1 Row, Straight Pin, Female Header | Mouser 437-8018300310003101
18 | 1 | L1 | MI0805K400R-10 | Laird Performance Materials | SMD/0805 | Ferrite Beads 40ohms 100MHz 1.5A Monolithic 0805 SMD | Mouser 875-MI0805K400R-10
19 | 1 | L2 | 1269AS-H-1R5M=P2 | Murata | SMD/2520 | Fixed Inductors 1.5uH 108mOhms2.1A +/-20% 2.5x2.0x1.0mm | Mouser 81-1269AS-H-1R5MP2
20 | 1 | PB1 | PTS645VM582LFS | C&K Switches | TH | Tactile Switch, Right Angle, Through Hole, 5.85mm stem, Momentary, 1.6N | Mouser 611-PTS645VM582
21 | 1 | PB2 | PTS645SM43SMTR92LFS | C&K Switches | SMD | Tactile Switch, Straight, SMD/SMT, 4.3mm stem, Momentary, 1.6N | Mouser 611-PTS645SM43SMTR92
22 | 2 | Q1, Q5 | NX7002AKVL | Nexperia | SMD/SOT23-3 | MOSFET 60V SGL N-CH TRENCHMOS | Mouser 771-NX7002AKVL
23 | 3 | Q2, Q3, Q4 | MMBT3094-7-F | Diodes Incorporated | SMD/SOT23-3 | Bipolar Transistors - BJT 40V NPN SS Trans 60Vceo 6Vebo 200mA | Mouser 621-MMBT3904-F
24 | 1 | Q6 | NX2301P,215 | Nexperia | SMD/SOT23-3 | MOSFET P-CH -20 V -2 A | Mouser 771-NX2301P215
25 | 1 | R1 | RC0603FR-074K7L | Yageo | SMD/0603 | Thick Film Resistors - SMD 4.7K OHM 1% | Mouser 603-RC0603FR-074K7L
26 | 18 | R2, R3, R15, R18, R21, R23, R25, R26, R27, R28, R29, R31, R32, R33, R34, R35, R38, R39 | RC0603FR-0710KL | Yageo | SMD/0603 | Thick Film Resistors - SMD 10K OHM 1% | Mouser 603-RC0603FR-0710KL
27 | 5 | R4, R17, R20, R22, R24 | RC0603FR-0715KL | Yageo | SMD/0603 | Thick Film Resistors - SMD 15K OHM 1% | Mouser 603-RC0603FR-0715KL
28 | 5 | R5, R7, R8, R14, R16 | RC0603FR-0740K2L | Yageo | SMD/0603 | Thick Film Resistors - SMD 40.2K OHM 1% | Mouser 603-RC0603FR-0740K2L
29 | 2 | R6, R30 | RC0603FR-072KL | Yageo | SMD/0603 | Thick Film Resistors - SMD 2K OHM 1% | Mouser 603-RC0603FR-072KL
30 | 3 | R9, R10, R19 | RC0603FR-071KL | Yageo | SMD/0603 | Thick Film Resistors - SMD 1K OHM 1% | Mouser 603-RC0603FR-071KL
31 | 1 | R11 | RC0603FR-071K54L | Yageo | SMD/0603 | Thick Film Resistors - SMD 1.54K OHM 1% | Mouser 603-RC0603FR-071K54L
32 | 1 | R12 | RC0603FR-0769K8L | Yageo | SMD/0603 | Thick Film Resistors - SMD 69.8K OHM 1% | Mouser 603-RC0603FR-0769K8L
33 | 1 | R13 | MM103J1K | Littlefuse | SMD/MicroMELF-2 | NTC Thermistors NTC THERMISTOR 10K OHM 10% MELF | Mouser 576-MM103J1K
34 | 2 | R36, R37 | RC0603FR-0733RL | Yageo | SMD/0603 | Thick Film Resistors - SMD 33 OHM 1% | Mouser 603-RC0603FR-0733RL
35 | 1 | U1 | FT232RL | FTDI | SMD/SSOP-28 | USB Interface IC USB to Serial UART Enhanced IC SSOP-28 | Mouser 895-FT232RL
36 | 1 | U2 | MCP73871-2CCI/ML | Microchip | SMD/QFN-20 | Battery Management USB/AC Battery Charger | Mouser 579-MCP73871-2CCI/ML
37 | 1 | U3 | TPS63051RMWR | Texas Instruments | SMD/VQFN-HR_12 | Switching Voltage Regulators | Mouser 595-TPS63051RMWR
38 | 1 | U4 | DS3232MZ | Maxim Integrated | SMD/SOIC-8 | Real Time Clock +/- 5PPM I2C TRC with MEMORY MEMS | Mouser 700-DS3232MZ+TRL
39 | 1 | U5 | ADC128D818CIMTX/NOPB | Texas Instruments | SMD/TSSOP-16 | Analog to Digital Converter | Mouser 926-A128D818CIMTXNPB
40 | 1 | U6 | LM4050AEM3-2.0/NOPB | Texas Instruments | SMD/SOT23-3 | Voltage References Prec MicroPwr Shunt, 2.048V | Mouser 926-LM4050AEM320NOPB
41 | 1 | ArduCAM | Mini-2MP Plus | Arducam | TH | Arducam Mini Module Camera Shield with OV2640 2 Megapixels + Lens | Buy from a source listed at https://www.arducam.com/distributors/
42 | 1 | PCB |  |  |  | 2-layer FR-4, 1.6mm, 1 oz copper, ENIG finish, Green solder mask, White Silkscreen |  | Panelization at discretion of CM

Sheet: FireCAM - Rev 03 - System Assy
FireCAM System Assembly - Rev 03
Line No | Qty | Ref Desg | Part Number | Manuf | Package/Type | Desc | Distributor Part Number | Notes
1 | 1 | BAT1 | ASR00050 | TinyCircuits | 18650 | Rechargeable 2500 mAh 3.7V Lithium Ion battery | Mouser 406-ASR00050
2 | 1 | BAT2 | BR1225 | Panasonic | BR1225 | Primary 48 mAh 3V Lithium Carbon Monofluoride battery | Mouser 658-BR1225
3 | 1 |  | 801-83-014-10-001101 | Preci-dip | TH | 14 Position, 2.54mm, 1 Row, Straight Pin, Female Header | Mouser 437-8018301410001101 | Female end for LCD cable assembly
4 | 1 |  | 22-28-4110 | Molex | TH | 11 Position, 2.54 mm, 1 Row, Straight Pin, Male breakaway header | Mouser 538-22-28-4110 | Male end for LCD cable assembly
5 | 1 |  | 22-28-4030 | Molex | TH | 3 Position, 2.54 mm, 1 Row, Straight Pin, Male breakaway header | Mouser 538-22-28-4110 | Male end for Temperature Sensor assembly
6 | 1 | TMP | TMP36GT9Z | Analog Device Inc | TH | Board Mount Temperature sensor | Mouser 584-TMP36GT9Z | Temperature sensor
7 | 8 |  | 561-MF440-25 | Eagle Plastic Devices | Hardware | Nylon Standoff, 1/4 in, 4-40 | Mouser 561-MF440-25
8 | 8 |  | 9605 | Keystone Electronics | Hardware | Nylon 4-40 Hex screw nut | Mouser 534-9605
9 | 8 |  | 561-P440.25 | Eagle Plastic Devices | Hardware | Nylon 4-40x1/4in Panhead Screw | Mouser 561-P440.25
10 | 4 |  | 4809 | Keystone Electronics | Hardware | Nylon Standoff, 1-3/8in, 4-40 | Mouser 534-4809
11 | 1 |  | 080-0001 | Laird Connectivity | Cable | RF Cable assembly U.FL to RP-SMA Bulkhead cable 105 mm | Mouser 741-080-0001
12 | 1 |  | RN-SMA-S-RP | Microchip | Antenna | Antenna 2.4 GHz 1” Stubby Rev Pol SMA | Mouser 765-RN-SMA-S-RP
13 | 1 | Lepton |  | GroupGets | Module | Pure Thermal breakout board with FLiR Lepton 3.5 Sensor | https://store.groupgets.com/collections/flir-lepton-accessories/products/purethermal-breakout-board
14 | 1 |  |  |  | Module | HiLetgo ILI9341 2.8” SPI TFT LCD Display Panel 240x320 with resistive touch | Can be found on Amazon
15 | 1 |  |  |  |  | Plexiglass sheet larger than 4” x 3”, 0.125” thick | Laser cut for LCD mount
16 |  |  |  |  |  | AWG28 wires for LCD and temperature sensor cable assemblies
17 |  |  |  |  |  | Shrink wrap tubing for cable assemblies

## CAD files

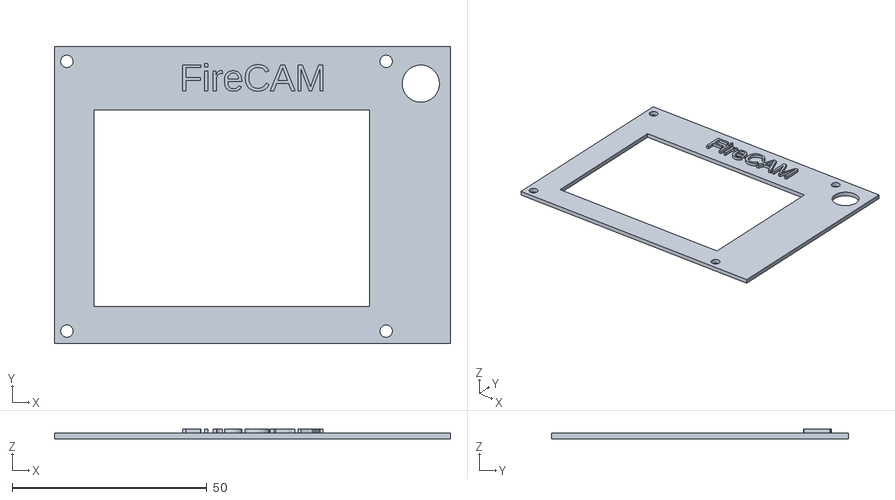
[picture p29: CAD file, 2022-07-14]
hardware/display_mount/3d_printed/display_mount_top.stl
101.6 x 76.2 x 2.50

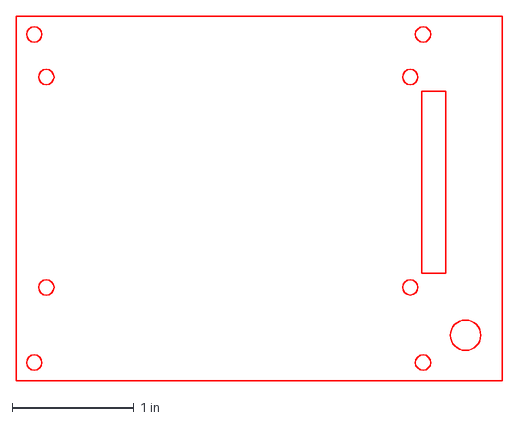
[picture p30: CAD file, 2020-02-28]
hardware/display_mount/laser_cut/display_mount.dxf
4.00 x 3.00 in

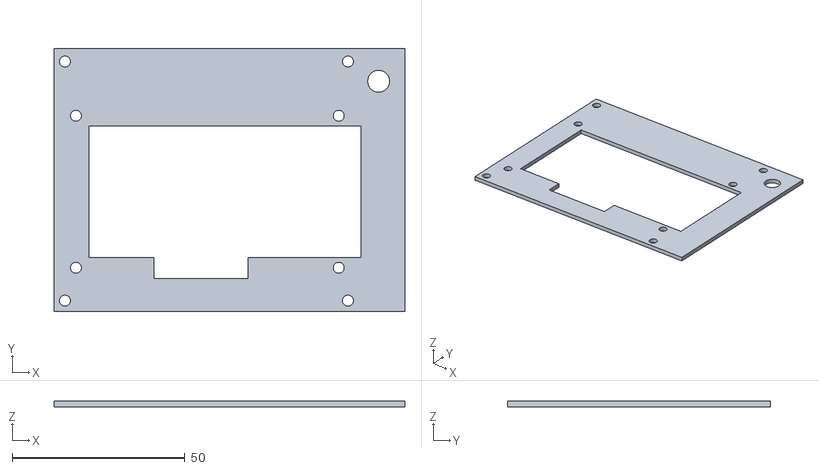
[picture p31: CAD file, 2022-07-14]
hardware/display_mount/3d_printed/display_mount_bot.stl
101.6 x 76.2 x 1.60

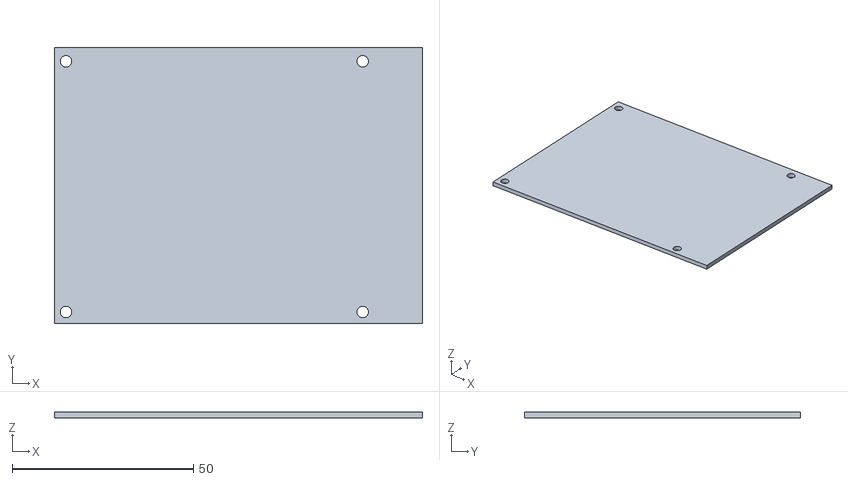
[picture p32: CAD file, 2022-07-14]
hardware/display_mount/3d_printed/bottom_mount.stl
101.6 x 76.2 x 1.60

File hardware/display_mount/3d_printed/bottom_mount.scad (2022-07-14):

//
// FireCAM bottom mount - converting imperial units to mm
//

// Mount width & length (inces)
bw = 4;
bl = 3;

// Bezel height (mm)
bh = 1.6;

// Mounting screw diameter (inches)
mh = 0.125;


module hole(x, y, d) {
    translate([x * 25.4, y * 25.4, -1]) {
        cylinder(h = bh+2, r = (d * 25.4)/2, $fn=120);
    }
}


difference() {
    // Plate
    cube([bw * 25.4, bl * 25.4, bh]);
    
    // PCB Mounting holes
    hole(0.125, 0.125, mh);
    hole(0.125, 2.85, mh);
    hole(3.35, 0.125, mh);
    hole(3.35, 2.85, mh);
}

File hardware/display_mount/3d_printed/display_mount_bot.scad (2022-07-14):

//
// FireCAM display bezel bottom part - converting imperial units to mm
//

// Bezel width & length (inces)
bw = 4;
bl = 3;

// Bezel height (mm)
bh = 1.6;

// Mounting screw diameter (inches)
mh = 0.125;

// Antenna mount diameter (inches)
ah = 0.250;

module hole(x, y, d) {
    translate([x * 25.4, y * 25.4, -1]) {
        cylinder(h = bh+2, r = (d * 25.4)/2, $fn=120);
    }
}


difference() {
    // Plate
    cube([bw * 25.4, bl * 25.4, bh]);
    
    // PCB Mounting holes
    hole(0.125, 0.125, mh);
    hole(0.125, 2.85, mh);
    hole(3.35, 0.125, mh);
    hole(3.35, 2.85, mh);
    
    // LCD Mounting holes
    hole(0.25, 0.5, mh);
    hole(0.25, 2.232, mh);
    hole(3.245, 0.5, mh);
    hole(3.245, 2.232, mh);
    
    // LCD circuitry cutout
    translate([0.4 * 25.4, 0.616 * 25.4, -1]) {
        cube([3.1 * 25.4, 1.5 * 25.4, bh + 2]);
    }
    
    // LCD SD Card connector cutout
    translate([1.14 * 25.4, 0.375 * 25.4, -1]) {
        cube([1.07 * 25.4, 0.5 * 25.4, bh + 2]);
    }
    
    // Antenna mounting hole
    hole(3.7, 2.625, ah);
}

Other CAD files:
hardware/display_mount/3d_printed/display_mount_top.scad

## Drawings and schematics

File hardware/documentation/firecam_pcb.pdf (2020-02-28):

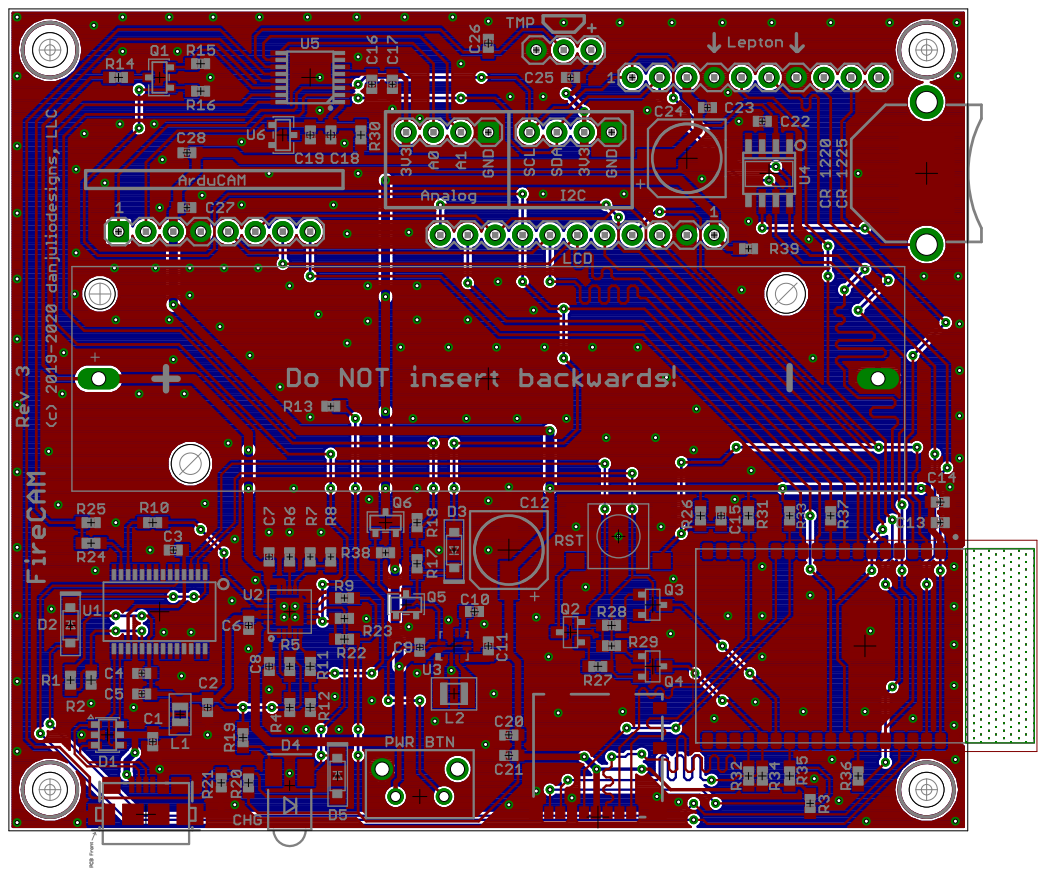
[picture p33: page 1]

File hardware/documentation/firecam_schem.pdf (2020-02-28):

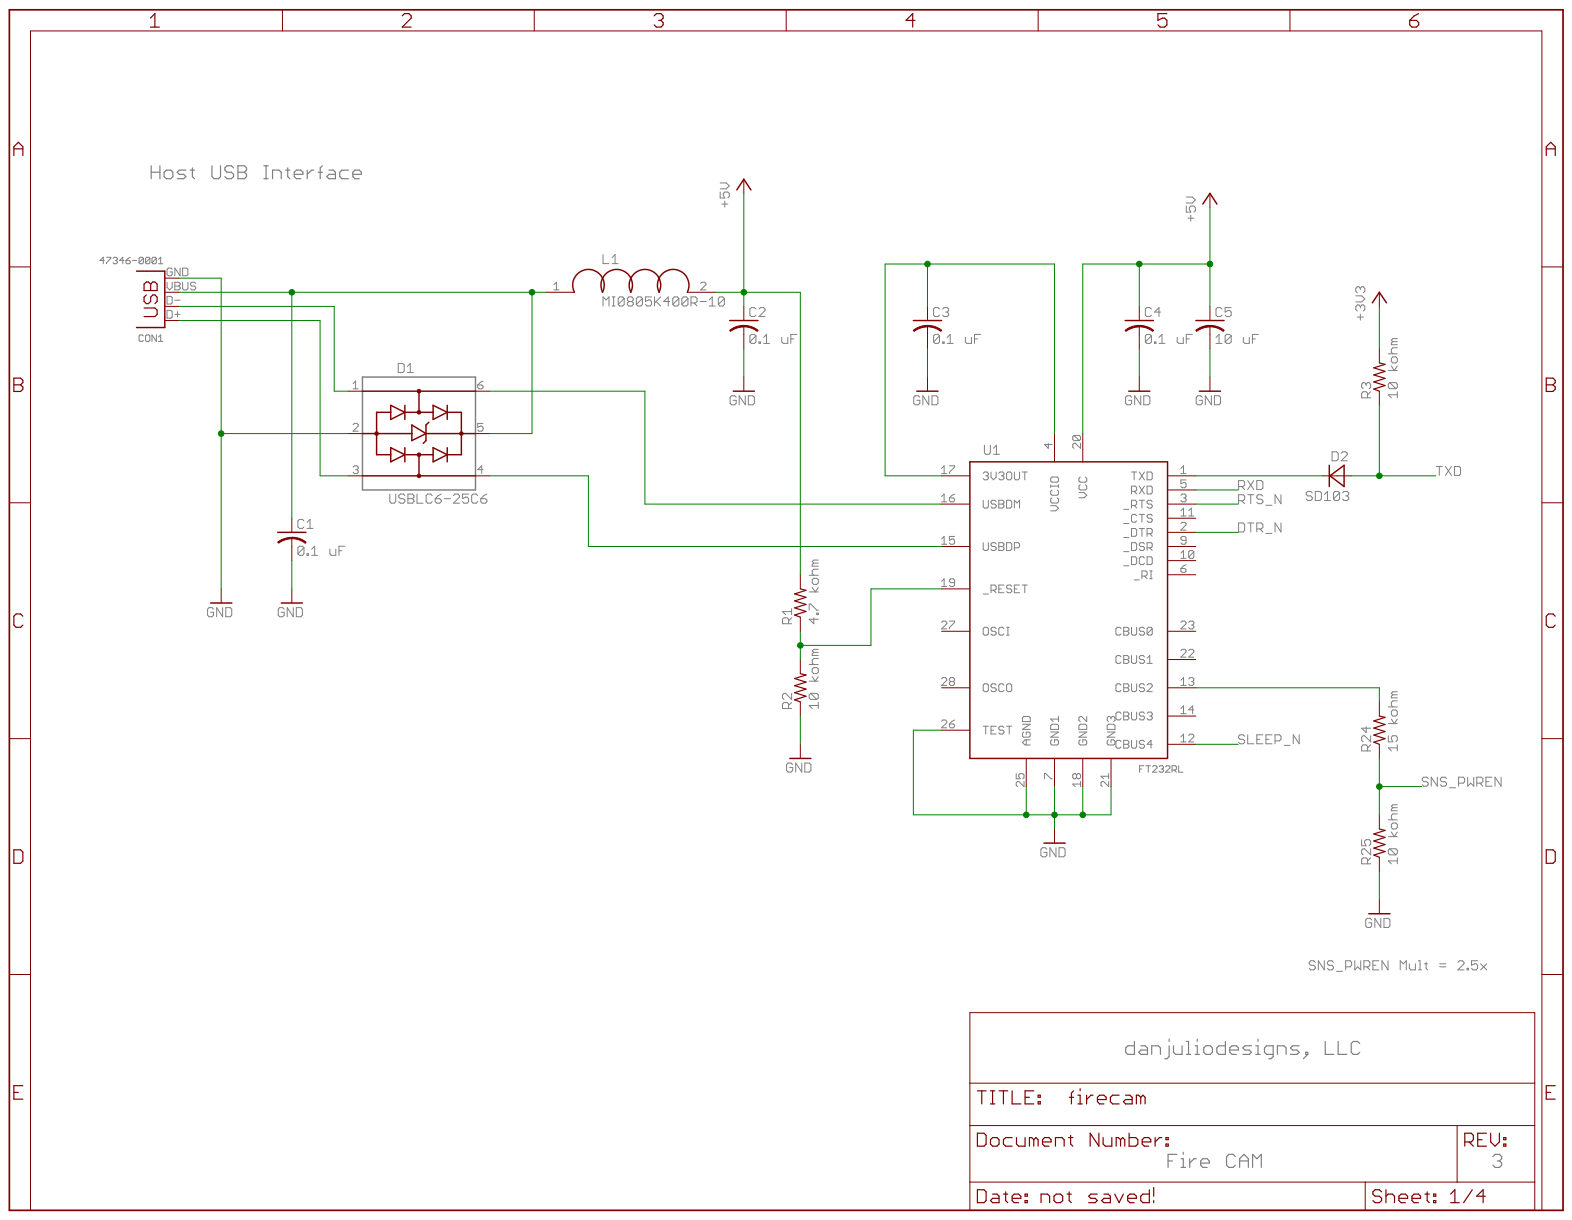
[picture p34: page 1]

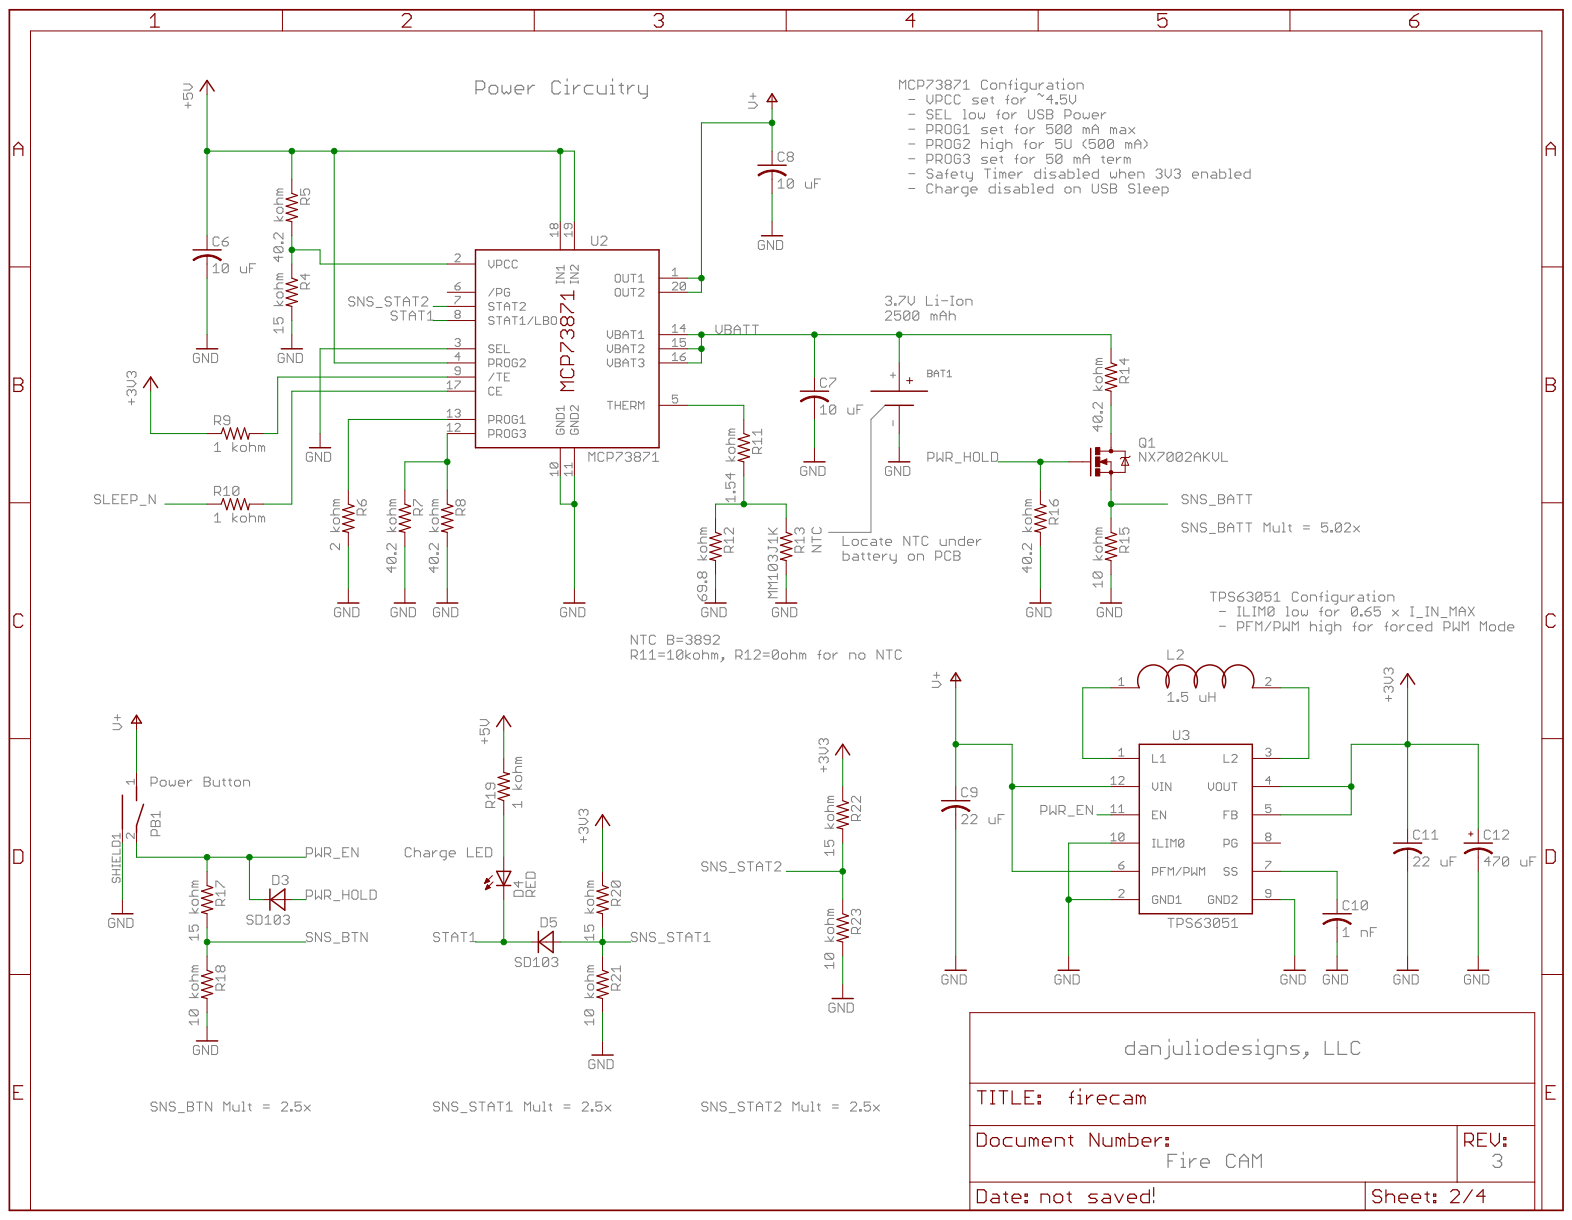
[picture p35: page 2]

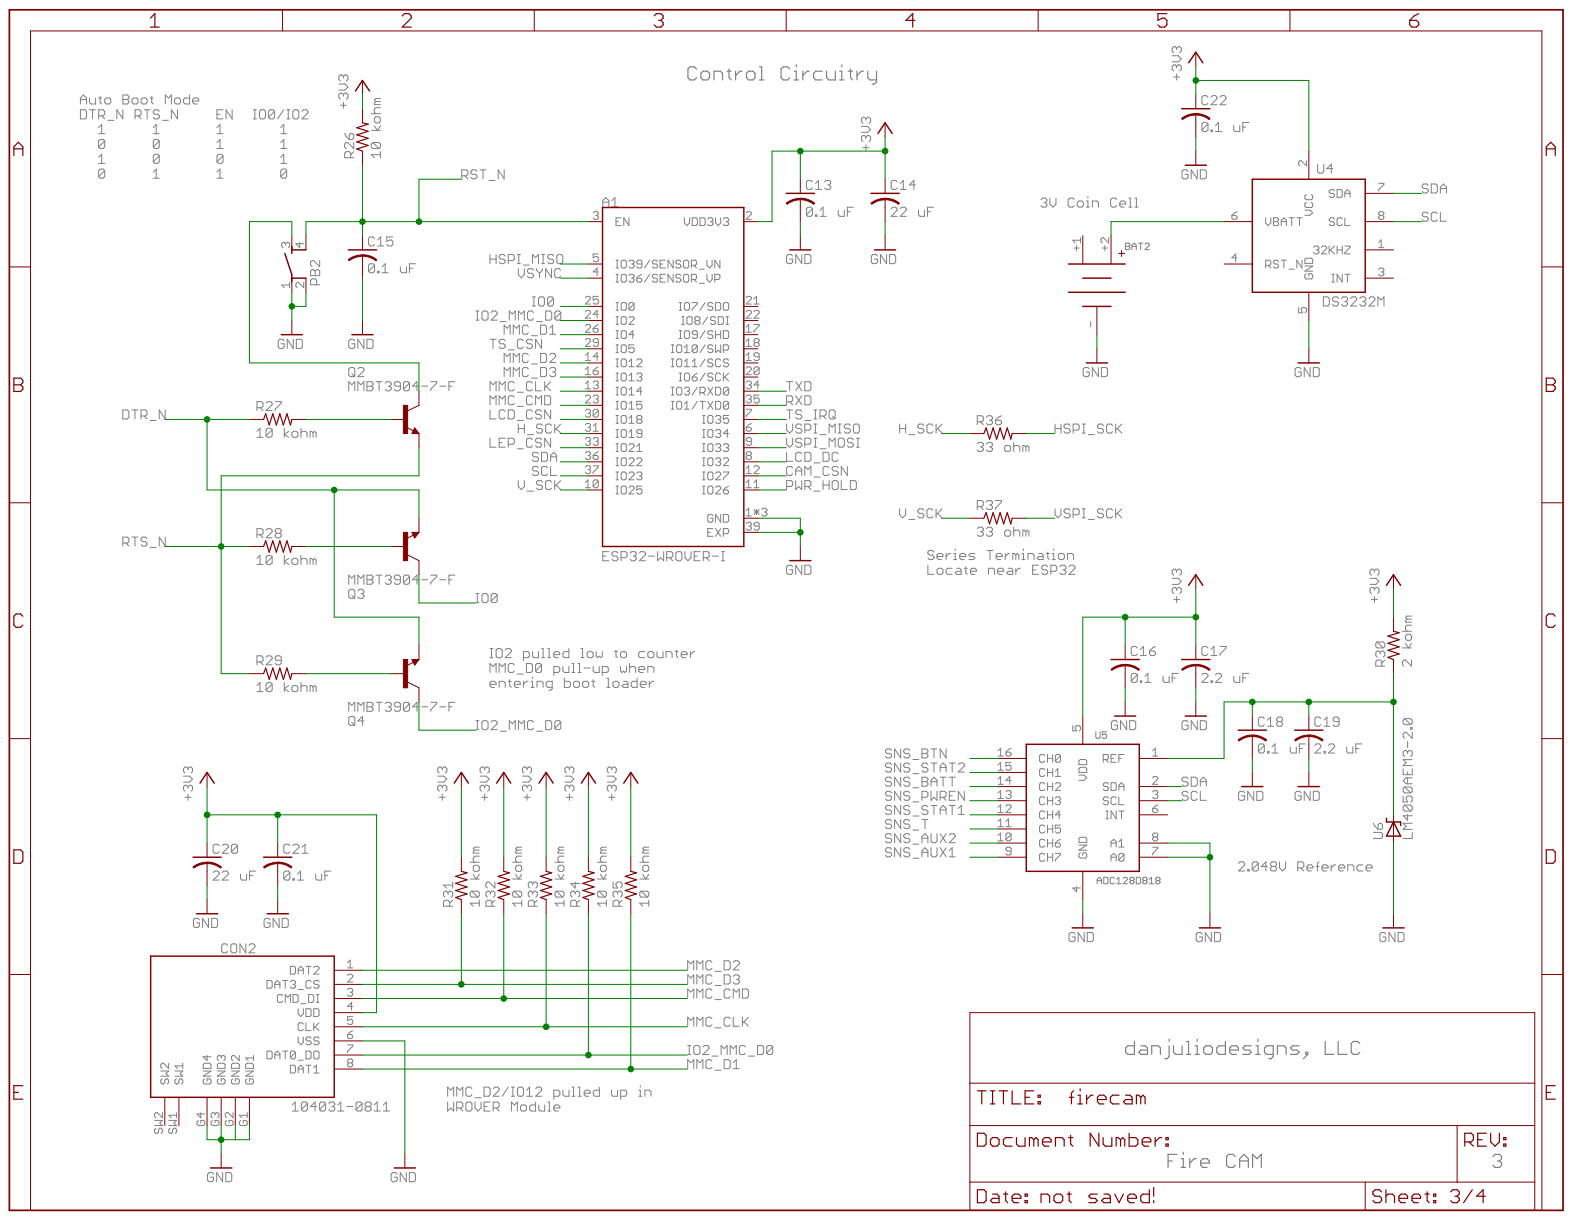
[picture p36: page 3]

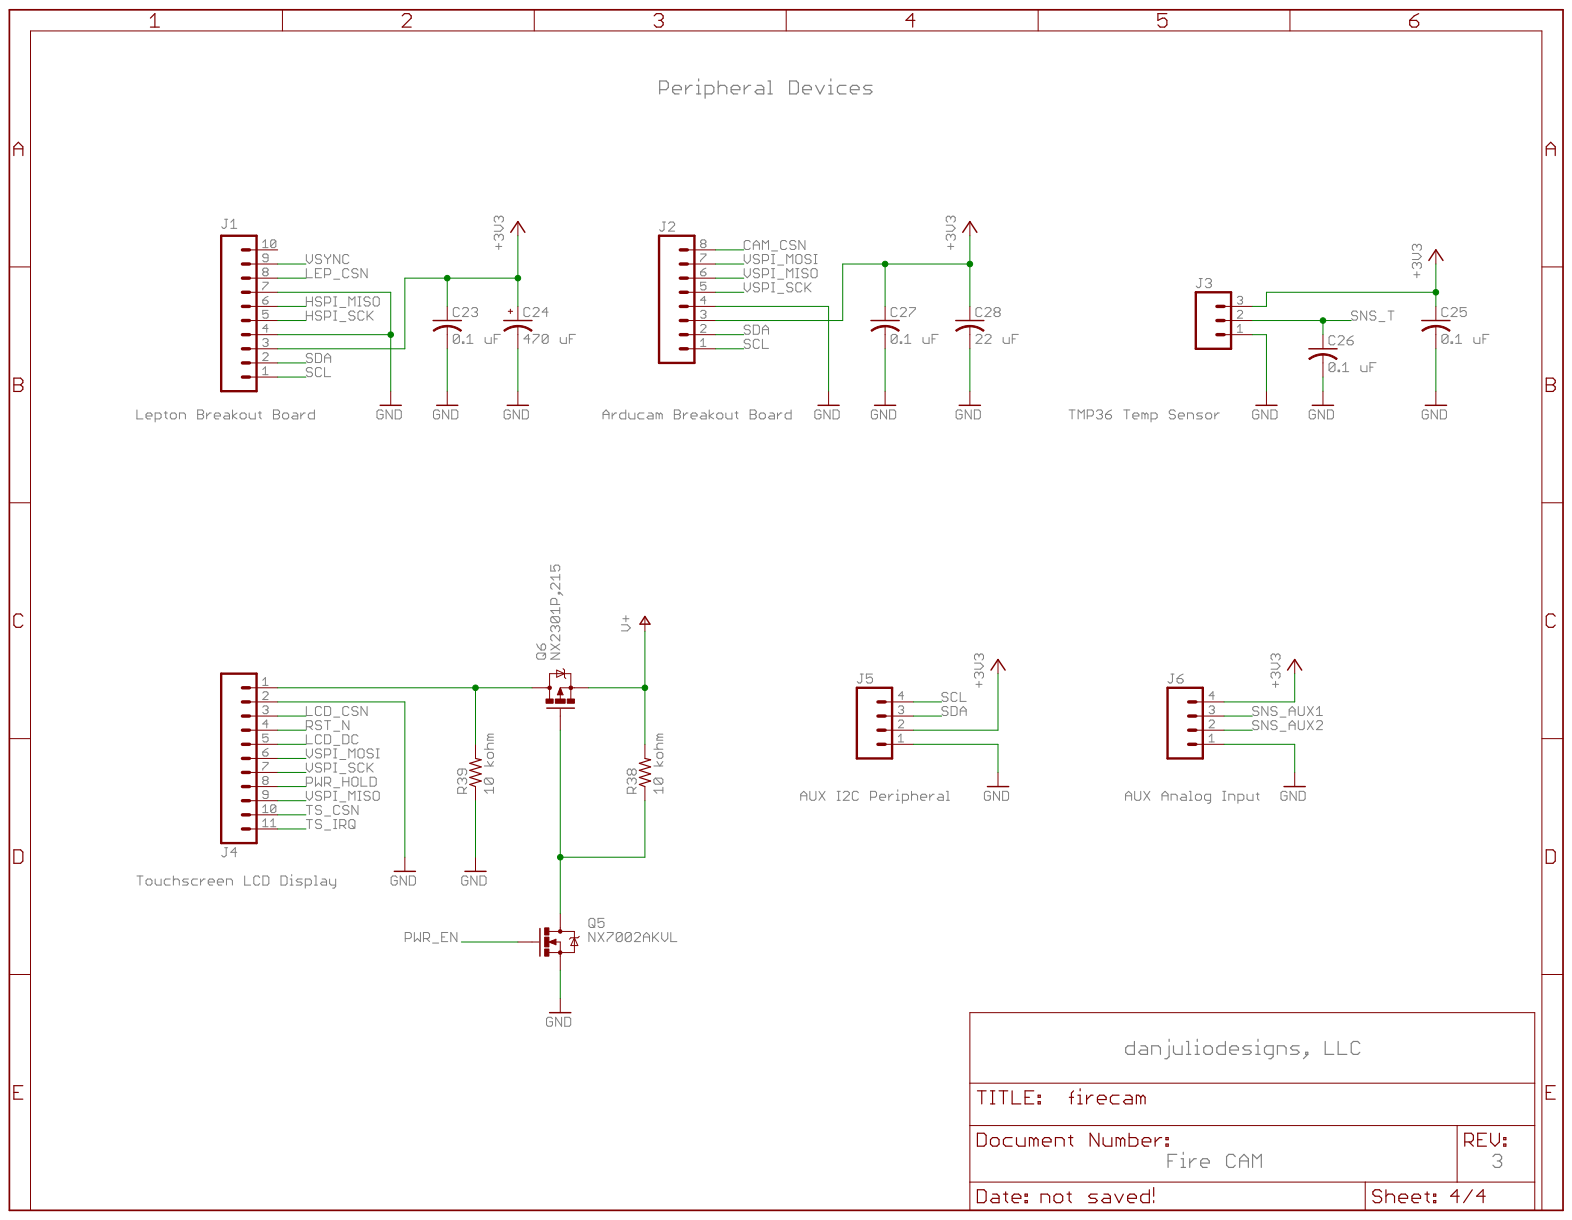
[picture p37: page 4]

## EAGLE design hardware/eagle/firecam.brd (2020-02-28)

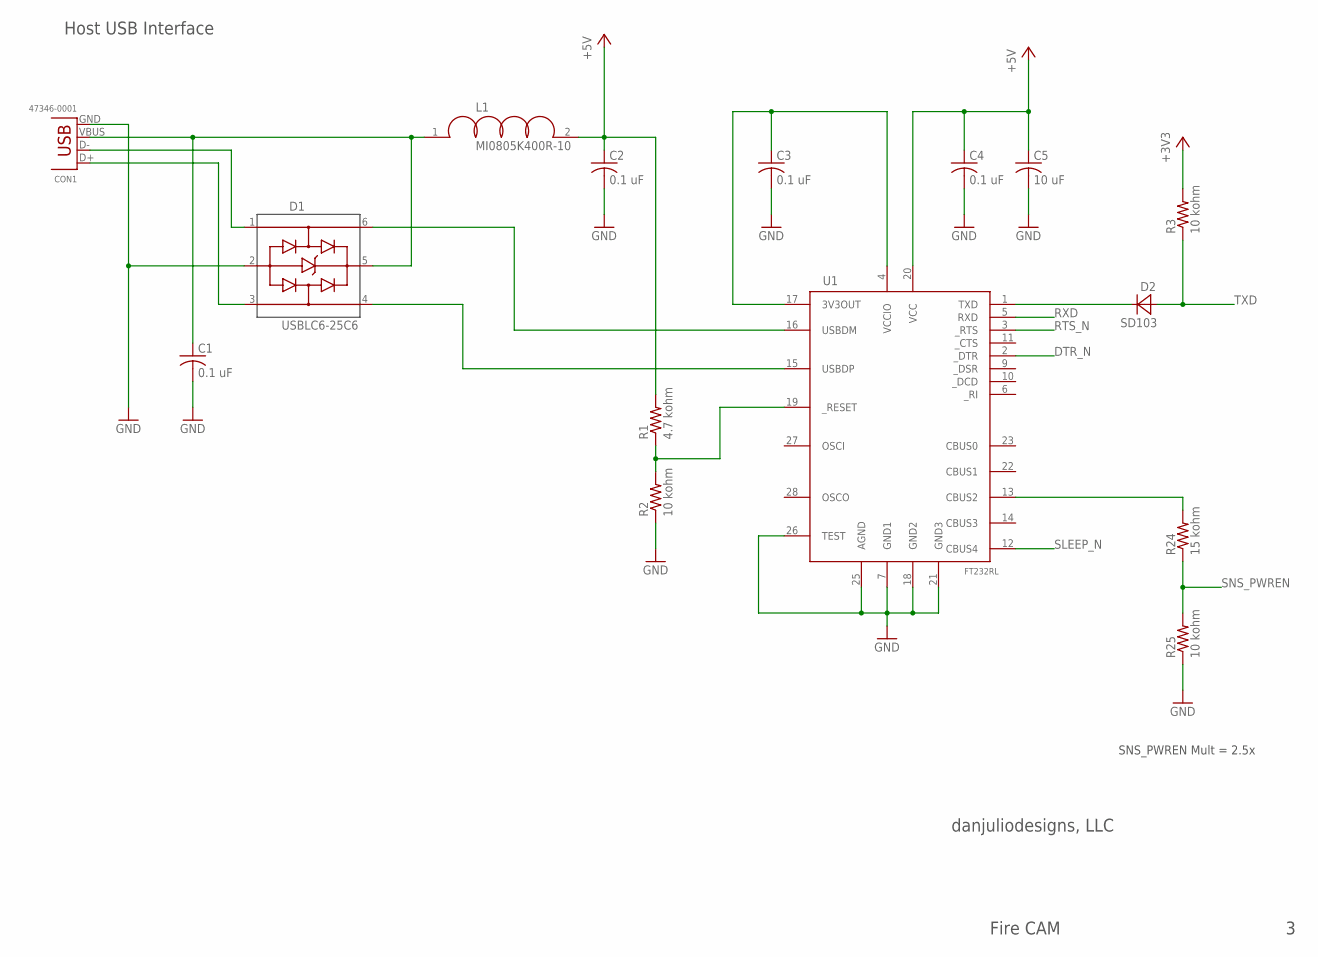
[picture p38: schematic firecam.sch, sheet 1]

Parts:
C1, C2, C3, C4: 0.1 uF; C0603
C5: 10 uF; C0603
CON1: 47346-0001; USB_MICROB_SMT
D1: USBLC6-25C6; SOT23-6
D2: SD103; SOD123
L1: MI0805K400R-10; L0805
R1: 4.7 kohm; R0603
R2, R3, R25: 10 kohm; R0603
R24: 15 kohm; R0603
U1: FT232RL; SSOP28DB

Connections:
+3V3: R3.2; also elsewhere on the board
+5V: C2.1, C4.1, C5.1, L1.2, R1.2, U1.20 (VCC); also elsewhere on the board
DTR_N: U1.2 (_DTR); also elsewhere on the board
GND: C1.2, C2.2, C3.2, C4.2, C5.2, CON1.GND, D1.2 (GND), R2.1, R25.1, U1.7 (GND1), U1.18 (GND2), U1.21 (GND3), U1.25 (AGND), U1.26 (TEST); also elsewhere on the board
unnamed: C1.1, CON1.VBUS, D1.5 (VBUS), L1.1
unnamed: CON1.D+, D1.3 (IO2)
unnamed: CON1.D-, D1.1 (IO1)
unnamed: C3.1, U1.4 (VCCIO), U1.17 (3V3OUT)
unnamed: D2.C, U1.1 (TXD)
unnamed: D1.6 (IO1$1), U1.16 (USBDM)
unnamed: D1.4 (IO2$1), U1.15 (USBDP)
unnamed: R1.1, R2.2, U1.19 (_RESET)
unnamed: R24.2, U1.13 (CBUS2)
RTS_N: U1.3 (_RTS); also elsewhere on the board
RXD: U1.5 (RXD); also elsewhere on the board
SLEEP_N: U1.12 (CBUS4); also elsewhere on the board
SNS_PWREN: R24.1, R25.2; also elsewhere on the board
TXD: D2.A, R3.1; also elsewhere on the board

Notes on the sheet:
danjuliodesigns, LLC
Fire CAM
Host USB Interface
SNS_PWREN Mult = 2.5x

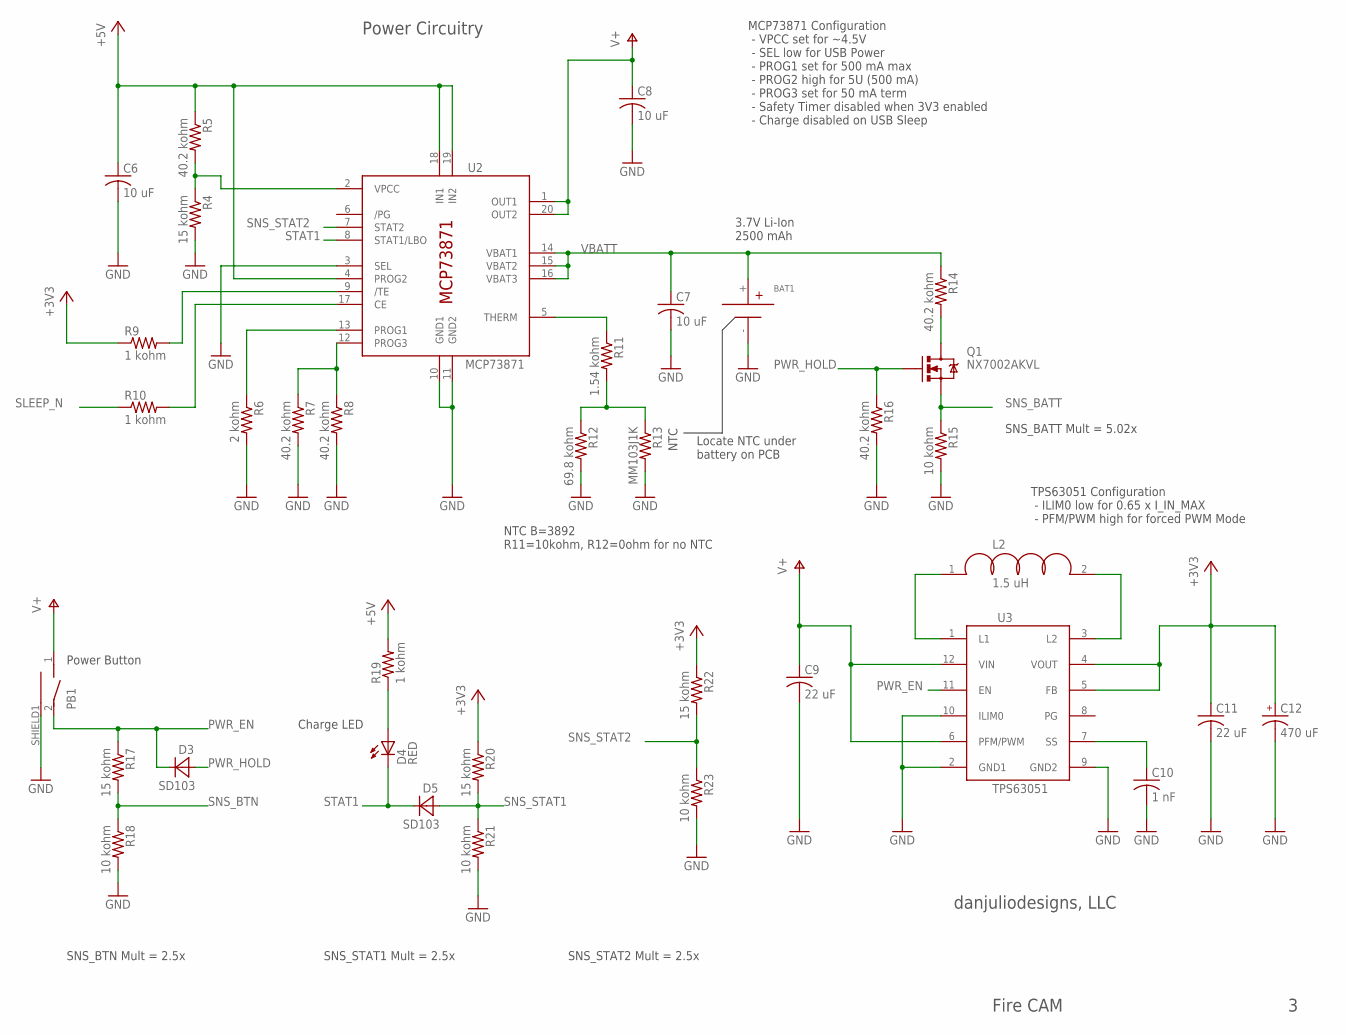
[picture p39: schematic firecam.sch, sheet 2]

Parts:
BAT1: 18650_BATTERYTH; KEYSTONE_1043
C6, C7, C8: 10 uF; C0603
C9, C11: 22 uF; C0603
C10: 1 nF; C0603
C12: 470 uF; ECAP-0606
D3, D5: SD103; SOD123
D4: RED; LUMEX_3MM_SMT
L2: 1.5 uH; L1008
PB1: PB_SMT_SIDEPTS645; PTS645_SIDE_TH
Q1: NX7002AKVL; SOT23-3
R4, R17, R20, R22: 15 kohm; R0603
R5, R7, R8, R14, R16: 40.2 kohm; R0603
R6: 2 kohm; R0603
R9, R10, R19: 1 kohm; R0603
R11: 1.54 kohm; R0603
R12: 69.8 kohm; R0603
R13: MM103J1K; R0603
R15, R18, R21, R23: 10 kohm; R0603
U2: MCP73871; QFN20
U3: TPS63051; HOTROD_QFN12

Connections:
+3V3: C11.1, C12.+ (1), R9.1, R20.1, R22.1, U3.4 (VOUT), U3.5 (FB); also elsewhere on the board
+5V: C6.1, R5.1, R19.2, U2.4 (PROG2), U2.18 (IN1), U2.19 (IN2); also elsewhere on the board
GND: BAT1.-, C6.2, C7.2, C8.2, C9.2, C10.2, C11.2, C12.- (2), PB1.SHIELD1 (CASE), R4.2, R6.2, R7.2, R8.2, R12.2, R13.2, R15.2, R16.2, R18.2, R21.2, R23.2, U2.3 (SEL), U2.10 (GND1), U2.11 (GND2), U3.2 (GND1), U3.9 (GND2), U3.10 (ILIM0); also elsewhere on the board
unnamed: R4.1, R5.2, U2.2 (VPCC)
unnamed: R6.1, U2.13 (PROG1)
unnamed: R7.1, R8.1, U2.12 (PROG3)
unnamed: R9.2, U2.9 (/TE)
unnamed: R10.2, U2.17 (CE)
unnamed: R11.1, U2.5 (THERM)
unnamed: L2.1, U3.1 (L1)
unnamed: Q1.3 (D), R14.2
unnamed: D4.P$1 (A), R19.1
unnamed: R11.2, R12.1, R13.1
unnamed: L2.2, U3.3 (L2)
unnamed: C10.1, U3.7 (SS)
PWR_EN: D3.C, PB1.2, R17.1, U3.11 (EN); also elsewhere on the board
PWR_HOLD: D3.A, Q1.1 (G), R16.1; also elsewhere on the board
SLEEP_N: R10.1; also elsewhere on the board
SNS_BATT: Q1.2 (S), R15.1; also elsewhere on the board
SNS_BTN: R17.2, R18.1; also elsewhere on the board
SNS_STAT1: D5.A, R20.2, R21.1; also elsewhere on the board
SNS_STAT2: R22.2, R23.1, U2.7 (STAT2); also elsewhere on the board
STAT1: D4.P$2 (C), D5.C, U2.8 (STAT1/LBO)
V+: C8.1, C9.1, PB1.1, U2.1 (OUT1), U2.20 (OUT2), U3.6 (PFM/PWM), U3.12 (VIN); also elsewhere on the board
VBATT: BAT1.+, C7.1, R14.1, U2.14 (VBAT1), U2.15 (VBAT2), U2.16 (VBAT3)

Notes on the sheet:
danjuliodesigns, LLC
Power Button
Charge LED
Fire CAM
Power Circuitry
3.7V Li-Ion 2500 mAh
MCP73871 Configuration - VPCC set for ~4.5V - SEL low for USB Power - PROG1 set for 500 mA max - PROG2 high for 5U (500 mA) - PROG3 set for 50 mA term - Safety Timer disabled when 3V3 enabled - Charge disabled on USB Sleep
TPS63051 Configuration - ILIM0 low for 0.65 x I_IN_MAX - PFM/PWM high for forced PWM Mode
NTC
Locate NTC under battery on PCB
SNS_BTN Mult = 2.5x
SNS_STAT1 Mult = 2.5x
SNS_STAT2 Mult = 2.5x
SNS_BATT Mult = 5.02x
NTC B=3892 R11=10kohm, R12=0ohm for no NTC

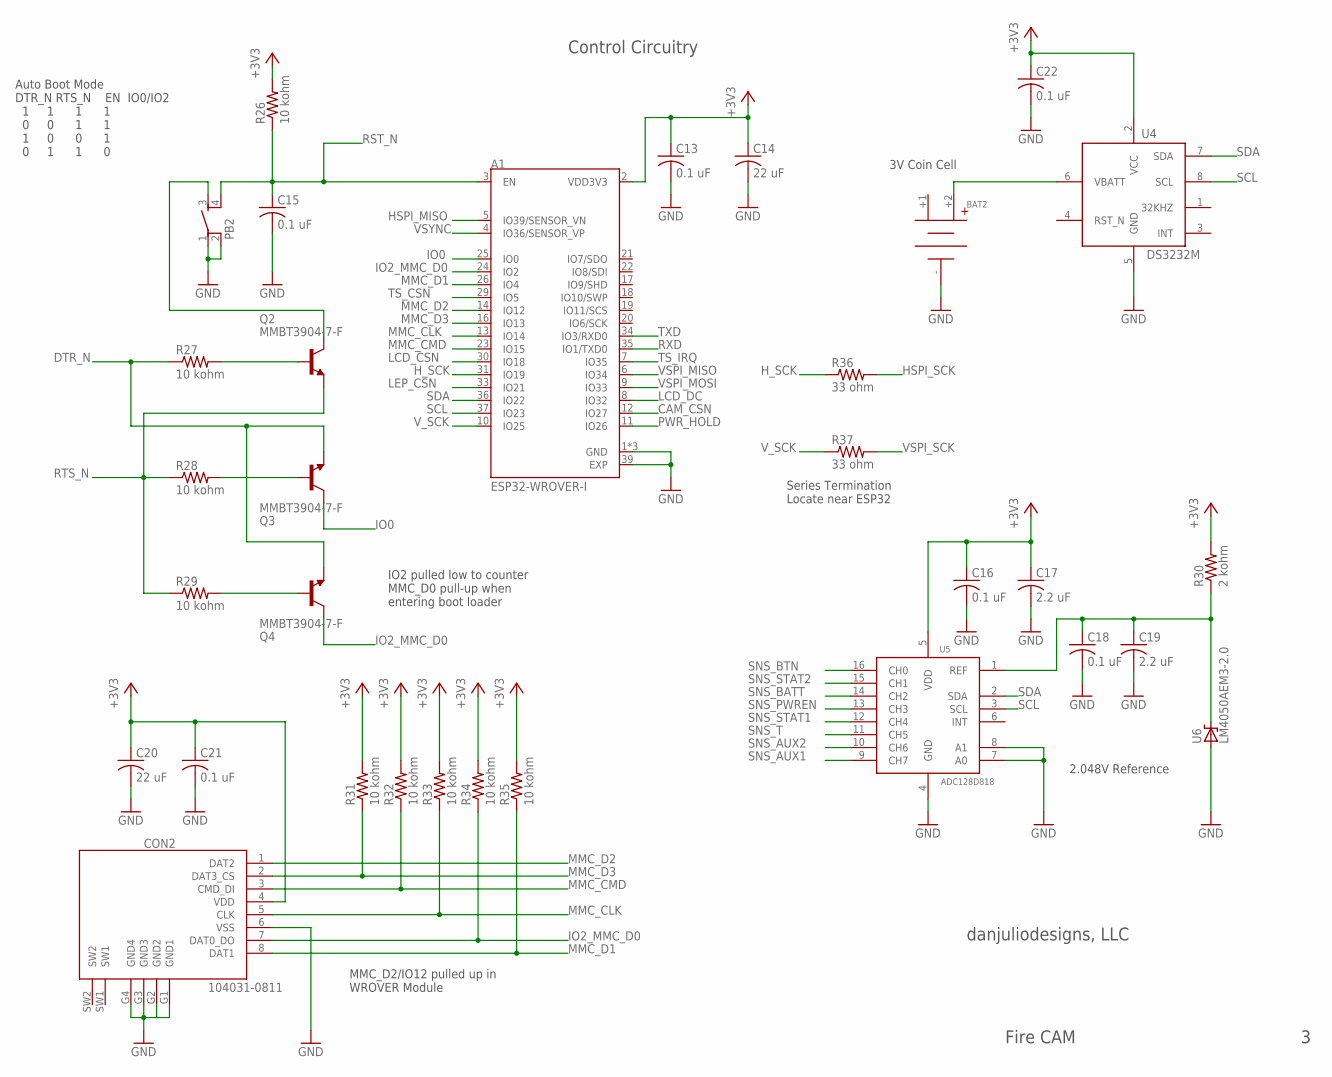
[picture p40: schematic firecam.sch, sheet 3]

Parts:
A1: ESP32-WROVER-I; XCVR_ESP32-WROVER-I
BAT2: COIN_CELL12MM; KEYSTONE_3001
C13, C15, C16, C18, C21, C22: 0.1 uF; C0603
C14, C20: 22 uF; C0603
C17, C19: 2.2 uF; C0603
CON2: 104031-0811; MOLEX_1040310811
PB2: PB_TACT_4SMTR92; CK_PTS645_SMT
Q2, Q3, Q4: MMBT3904-7-F; SOT23-BEC
R26, R27, R28, R29, R31, R32, R33, R34, R35: 10 kohm; R0603
R30: 2 kohm; R0603
R36, R37: 33 ohm; R0603
U4: DS3232M; SO8
U5: ADC128D818; SSOP16
U6: LM4050AEM3-2.0; SOT23-3

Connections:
+1: BAT2.+1
+3V3: A1.2 (VDD3V3), C13.1, C14.1, C16.1, C17.1, C20.1, C21.1, C22.1, CON2.4 (VDD), R26.2, R30.2, R31.2, R32.2, R33.2, R34.2, R35.2, U4.2 (VCC), U5.5 (VDD); also elsewhere on the board
CAM_CSN: A1.12 (IO27); also elsewhere on the board
DTR_N: Q3.E, Q4.E, R27.1; also elsewhere on the board
GND: A1.1 (GND), A1.15 (GND), A1.38 (GND), A1.39 (EXP), BAT2.-, C13.2, C14.2, C15.2, C16.2, C17.2, C18.2, C19.2, C20.2, C21.2, C22.2, CON2.6 (VSS), CON2.G1 (GND1), CON2.G2 (GND2), CON2.G3 (GND3), CON2.G4 (GND4), PB2.1, PB2.2, U4.5 (GND), U5.4 (GND), U5.7 (A0), U5.8 (A1), U6.2 (A); also elsewhere on the board
HSPI_MISO: A1.5 (IO39/SENSOR_VN); also elsewhere on the board
HSPI_SCK: R36.2; also elsewhere on the board
H_SCK: A1.31 (IO19), R36.1
IO0: A1.25 (IO0), Q3.C
IO2_MMC_D0: A1.24 (IO2), CON2.7 (DAT0_DO), Q4.C, R34.1
LCD_CSN: A1.30 (IO18); also elsewhere on the board
LCD_DC: A1.8 (IO32); also elsewhere on the board
LEP_CSN: A1.33 (IO21); also elsewhere on the board
MMC_CLK: A1.13 (IO14), CON2.5 (CLK), R33.1
MMC_CMD: A1.23 (IO15), CON2.3 (CMD_DI), R32.1
MMC_D1: A1.26 (IO4), CON2.8 (DAT1), R35.1
MMC_D2: A1.14 (IO12), CON2.1 (DAT2)
MMC_D3: A1.16 (IO13), CON2.2 (DAT3_CS), R31.1
unnamed: C18.1, C19.1, R30.1, U5.1 (REF), U6.1 (C)
unnamed: BAT2.+2, U4.6 (VBATT)
unnamed: PB2.3, Q2.C
unnamed: Q2.B, R27.2
unnamed: Q3.B, R28.2
unnamed: Q4.B, R29.2
PWR_HOLD: A1.11 (IO26); also elsewhere on the board
RST_N: A1.3 (EN), C15.1, PB2.4, R26.1; also elsewhere on the board
RTS_N: Q2.E, R28.1, R29.1; also elsewhere on the board
RXD: A1.35 (IO1/TXD0); also elsewhere on the board
SCL: A1.37 (IO23), U4.8 (SCL), U5.3 (SCL); also elsewhere on the board
SDA: A1.36 (IO22), U4.7 (SDA), U5.2 (SDA); also elsewhere on the board
SNS_AUX1: U5.9 (CH7); also elsewhere on the board
SNS_AUX2: U5.10 (CH6); also elsewhere on the board
SNS_BATT: U5.14 (CH2); also elsewhere on the board
SNS_BTN: U5.16 (CH0); also elsewhere on the board
SNS_PWREN: U5.13 (CH3); also elsewhere on the board
SNS_STAT1: U5.12 (CH4); also elsewhere on the board
SNS_STAT2: U5.15 (CH1); also elsewhere on the board
SNS_T: U5.11 (CH5); also elsewhere on the board
TS_CSN: A1.29 (IO5); also elsewhere on the board
TS_IRQ: A1.7 (IO35); also elsewhere on the board
TXD: A1.34 (IO3/RXD0); also elsewhere on the board
VSPI_MISO: A1.6 (IO34); also elsewhere on the board
VSPI_MOSI: A1.9 (IO33); also elsewhere on the board
VSPI_SCK: R37.2; also elsewhere on the board
VSYNC: A1.4 (IO36/SENSOR_VP); also elsewhere on the board
V_SCK: A1.10 (IO25), R37.1

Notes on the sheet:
IO2 pulled low to counter MMC_D0 pull-up when entering boot loader
Auto Boot Mode DTR_N RTS_N EN IO0/IO2 1 1 1 1 0 0 1 1 1 0 0 1 0 1 1 0
MMC_D2/IO12 pulled up in WROVER Module
Control Circuitry
3V Coin Cell
Series Termination Locate near ESP32
2.048V Reference
danjuliodesigns, LLC
Fire CAM

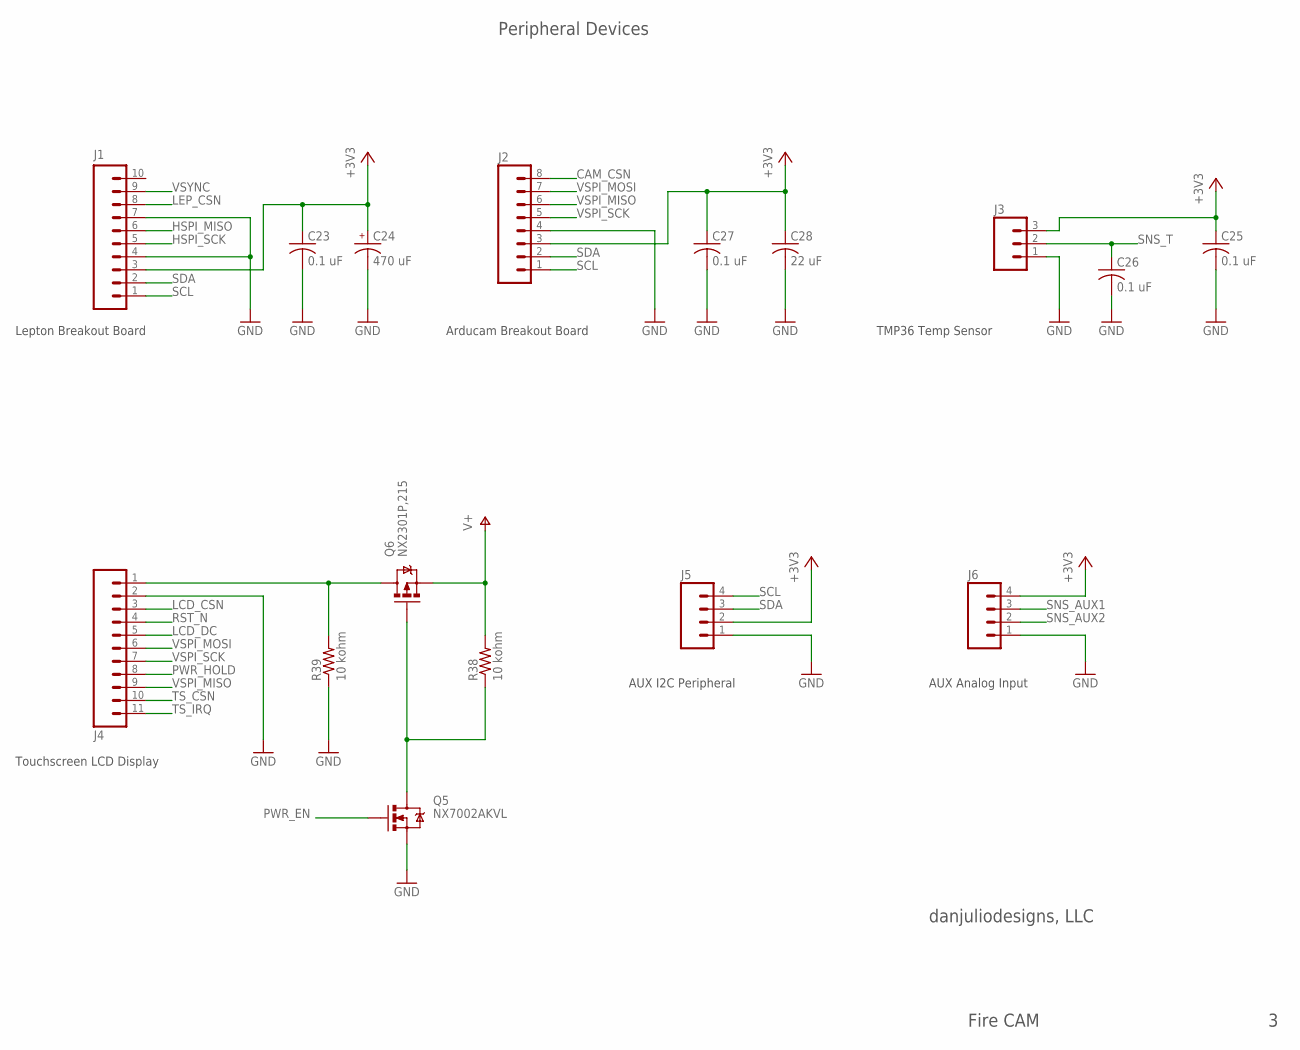
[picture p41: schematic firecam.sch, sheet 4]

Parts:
C23, C25, C26, C27: 0.1 uF; C0603
C24: 470 uF; ECAP-0606
C28: 22 uF; C0603
J1: M10SILK_FEMALE_PTH; 1X10
J2: M08SILK_FEMALE_PTH; 1X08
J3: M03PTH; 1X03
J4: M11PTH; 1X11
J5, J6: M04PTH; 1X04
Q5: NX7002AKVL; SOT23-3
Q6: NX2301P,215; SOT23-3
R38, R39: 10 kohm; R0603

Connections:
+3V3: C23.1, C24.+ (1), C25.1, C27.1, C28.1, J1.3, J2.3, J3.3, J5.2, J6.4; also elsewhere on the board
CAM_CSN: J2.8; also elsewhere on the board
GND: C23.2, C24.- (2), C25.2, C26.2, C27.2, C28.2, J1.4, J1.7, J2.4, J3.1, J4.2, J5.1, J6.1, Q5.2 (S), R39.1; also elsewhere on the board
HSPI_MISO: J1.6; also elsewhere on the board
HSPI_SCK: J1.5; also elsewhere on the board
LCD_CSN: J4.3; also elsewhere on the board
LCD_DC: J4.5; also elsewhere on the board
LEP_CSN: J1.8; also elsewhere on the board
unnamed: J4.1, Q6.3 (D), R39.2
unnamed: Q5.3 (D), Q6.1 (G), R38.1
PWR_EN: Q5.1 (G); also elsewhere on the board
PWR_HOLD: J4.8; also elsewhere on the board
RST_N: J4.4; also elsewhere on the board
SCL: J1.1, J2.1, J5.4; also elsewhere on the board
SDA: J1.2, J2.2, J5.3; also elsewhere on the board
SNS_AUX1: J6.3; also elsewhere on the board
SNS_AUX2: J6.2; also elsewhere on the board
SNS_T: C26.1, J3.2; also elsewhere on the board
TS_CSN: J4.10; also elsewhere on the board
TS_IRQ: J4.11; also elsewhere on the board
V+: Q6.2 (S), R38.2; also elsewhere on the board
VSPI_MISO: J2.6, J4.9; also elsewhere on the board
VSPI_MOSI: J2.7, J4.6; also elsewhere on the board
VSPI_SCK: J2.5, J4.7; also elsewhere on the board
VSYNC: J1.9; also elsewhere on the board

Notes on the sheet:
Lepton Breakout Board
Arducam Breakout Board
TMP36 Temp Sensor
AUX I2C Peripheral
Touchscreen LCD Display
AUX Analog Input
Peripheral Devices
danjuliodesigns, LLC
Fire CAM

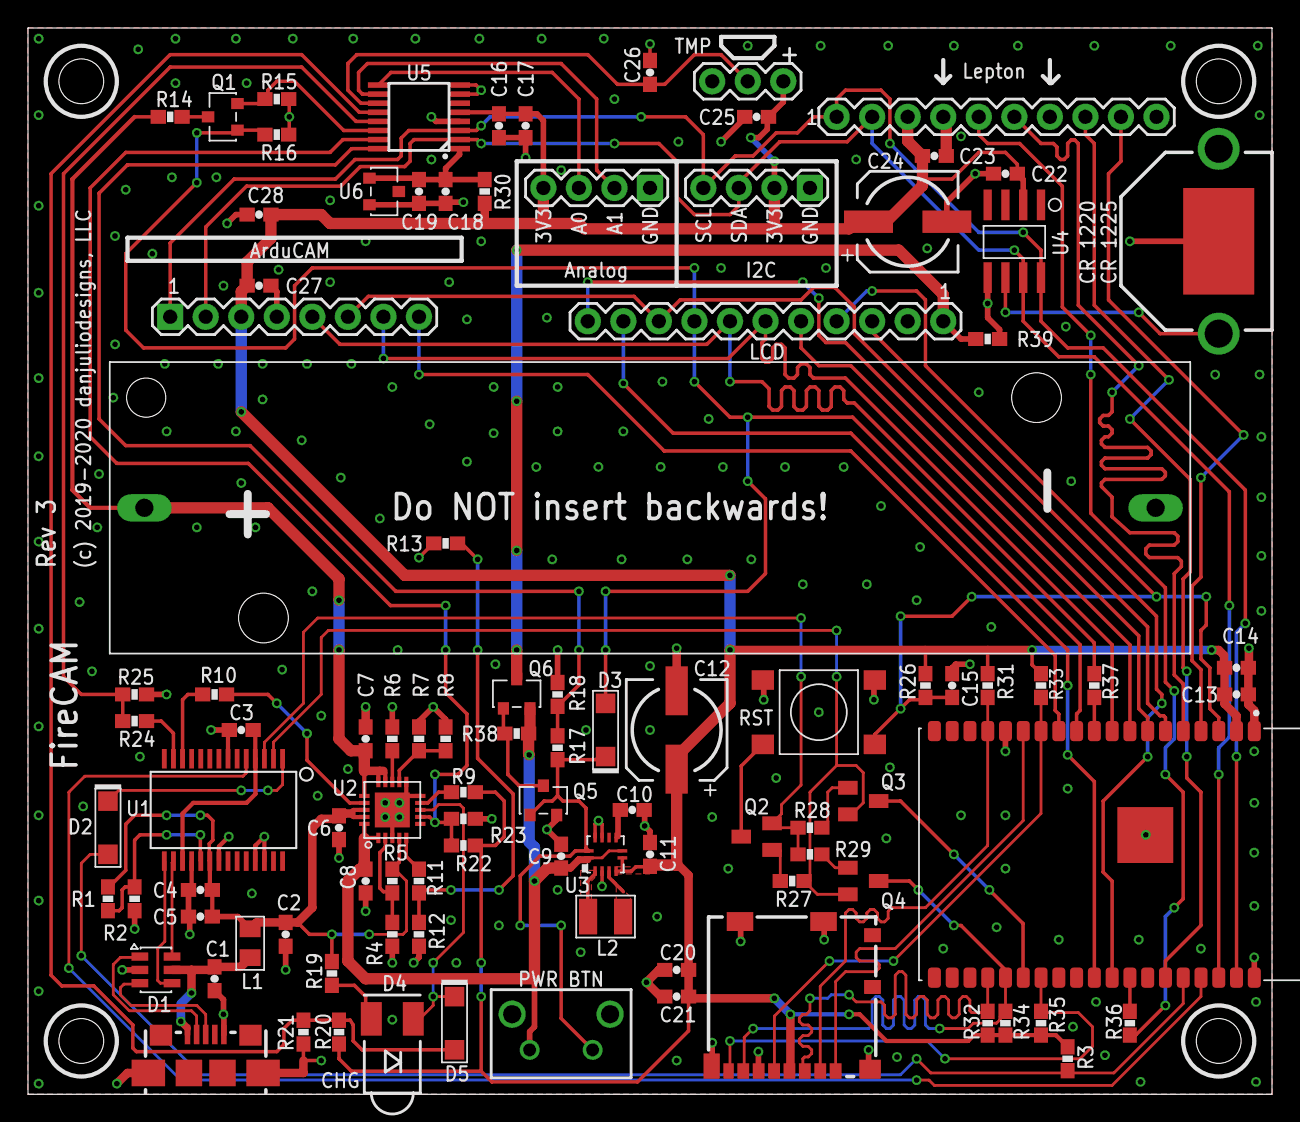
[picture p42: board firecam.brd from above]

Board: 2 copper layers, 88.9 x 76.2 mm, 99 parts (0 on the bottom side), 74 nets.

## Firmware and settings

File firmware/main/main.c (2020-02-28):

/*
 * FireCAM Main
 *
 * FireCAM is a timelapse camera system designed to capture both visual and radiometric
 * images and store them to a local SD Card.  It is designed to run on the FireCAM
 * system designed by danjuliodesigns, LLC.  It includes support for the following
 * peripherals:
 *   1. ESP32 WROVER-B with at least 4 MB SPI Flash and 4 MB SPI RAM
 *   2. ArduCAM Mini-2MP Plus jpeg camera
 *   3. FLiR Lepton 3.5 thermal imaging camera
 *   4. 320x240 Pixel 16-bit LCD controlled by an ILI9341 display controller
 *   5. Resistive touchpad controlled by a XPT2046 controller
 *   6. Battery-backed DS3232 Realtime clock with SRAM
 *   7. TI ADC128D818 8-channel 12-bit ADC with external 2.048 volt precision reference
 *      - External LM36 temperature sensor
 *   8. Micro-SD card
 *
 * This firmware provides the following high-level functionality:
 *   1. Record Mode to store image metadata, jpeg visual image, 16-bit radiometric raw
 *      data as a json object serialized as a text file on the SD Card.
 *   2. GUI displaying current camera images and controls for operating the camera and
 *      setting various operating parameters.
 *   3. Remote access via a socket exposed on the ESP32 WiFi interface for querying the
 *      camera and setting record mode and operating parameters.  Packets are encoded
 *      a textually serialized json objects.
 *   4. Soft-power pushbutton control, battery voltage detection and automatic low-battery
 *      shutdown.
 *   5. Time/Date and parameter storage in an externally battery-backed RTC.
 *   6. Operational and error logging to USB Serial interface.
 *   7. Auto-restart on camera crash and automatic restart of recording.
 *
 * Copyright 2020 Dan Julio
 *
 * This file is part of firecam.
 *
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
 * You should have received a copy of the GNU General Public License
 * along with firecam.  If not, see <https://www.gnu.org/licenses/>.
 */
#include <stdio.h>
#include "freertos/FreeRTOS.h"
#include "freertos/task.h"
#include "esp_log.h"
#include "adc_task.h"
#include "app_task.h"
#include "cam_task.h"
#include "cmd_task.h"
#include "file_task.h"
#include "gui_task.h"
#include "lep_task.h"
#include "mon_task.h"
#include "system_config.h"
#include "sys_utilities.h"



static const char* TAG = "main";

void app_main(void)
{
    ESP_LOGI(TAG, "FireCAM startup");
    
    // Initialize the ESP32 IO pins, set PWR_EN to keep us powered up and initialize
    // the shared SPI and I2C drivers
    if (!system_esp_io_init()) {
    	ESP_LOGE(TAG, "FireCAM ESP32 init failed - shutting off");
    	system_shutoff();
    }
    
    // After the IO has been set, holding power on, delay for > 950 mSec to allow
    // the both the ArduCAM and Lepton to finish booting so the ArduCAM is accessible
    // and the Lepton doesn't get confused by I2C traffic to other peripherals.
    vTaskDelay(pdMS_TO_TICKS(1000));
    
    // Initialize the camera's peripheral devices: RTC, ADC, Arducam, Lepton
    if (!system_peripheral_init()) {
    	ESP_LOGE(TAG, "FireCAM Peripheral init failed - shutting off");
    	system_shutoff();
    }
    
    // Pre-allocate big buffers
    if (!system_buffer_init()) {
    	ESP_LOGE(TAG, "FireCAM memory allocate failed - shutting off");
    	system_shutoff();
    }
    
    // Initialized: Start tasks
    xTaskCreatePinnedToCore(&adc_task,  "adc_task",  2048, NULL, 1, &task_handle_adc,  1);
    xTaskCreatePinnedToCore(&cam_task,  "cam_task",  2048, NULL, 2, &task_handle_cam,  1);
    xTaskCreatePinnedToCore(&cmd_task,  "cmd_task",  3072, NULL, 1, &task_handle_cmd,  0);
    xTaskCreatePinnedToCore(&file_task, "file_task", 3072, NULL, 1, &task_handle_file, 1);
    xTaskCreatePinnedToCore(&gui_task,  "gui_task",  3072, NULL, 1, &task_handle_gui,  1);
    xTaskCreatePinnedToCore(&lep_task,  "lep_task",  2048, NULL, 2, &task_handle_lep,  0);
    xTaskCreatePinnedToCore(&app_task,  "app_task",  3072, NULL, 1, &task_handle_app,  1);
#ifdef INCLUDE_SYS_MON
	xTaskCreatePinnedToCore(&mon_task,  "mon_task",  2048, NULL, 1, &task_handle_mon,  1);
#endif
}

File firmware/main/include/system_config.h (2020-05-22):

/*
 * System Configuration File
 *
 * Contains system definition and configurable items.
 *
 * Copyright 2020 Dan Julio
 *
 * This file is part of firecam.
 *
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
 */
#ifndef SYSTEM_CONFIG_H
#define SYSTEM_CONFIG_H

#include "esp_system.h"
#include "cci.h"
#include "ov2640.h"


// ======================================================================================
// System debug
//

// Undefine to include the system monitoring task (included only for debugging/tuning)
//#define INCLUDE_SYS_MON



// ======================================================================================
// System hardware definitions
//

//
// IO Pins
//   Lepton uses HSPI (no MOSI)
//   ArduCam, LCD and TS use VSPI
//
#define TS_CSN_IO         5
#define LCD_CSN_IO        18
#define HSPI_SCK_IO       19
#define LEP_CSN_IO        21
#define I2C_MASTER_SDA_IO 22
#define I2C_MASTER_SCL_IO 23
#define VSPI_SCK_IO       25
#define PWR_HOLD_IO       26
#define CAM_CSN_IO        27
#define LCD_DC_IO         32
#define VSPI_MOSI_IO      33
#define VSPI_MISO_IO      34
#define TS_IRQ_IO         35
#define LEP_VSYNC_IO      36
#define HSPI_MISO_IO      39


//
// Hardware Configuration
//

// I2C
#define I2C_MASTER_NUM     1
#define I2C_MASTER_FREQ_HZ 100000

// SPI
#define LEP_SPI_HOST    HSPI_HOST
#define CAM_SPI_HOST    VSPI_HOST
#define LCD_SPI_HOST    VSPI_HOST
#define TS_SPI_HOST     VSPI_HOST
#define HSPI_DMA_NUM    1
#define VSPI_DMA_NUM    2
#define LEP_SPI_FREQ_HZ 16000000
#define LCD_SPI_FREQ_HZ 16000000
#define CAM_SPI_FREQ_HZ  4000000
#define TS_SPI_FREQ_HZ   2000000


// ======================================================================================
// System configuration
//

// Little VGL buffer update size
#define LVGL_DISP_BUF_SIZE (320 * 40)

// Little VGL Touchpanel configuration (a bit of a hack - it should be calibrated)
#define LVGL_TOUCH_X_MIN    360
#define LVGL_TOUCH_Y_MIN    270
#define LVGL_TOUCH_X_MAX    3900
#define LVGL_TOUCH_Y_MAX    3800
#define LVGL_TOUCH_INVERT_X 1
#define LVGL_TOUCH_INVERT_Y 1

// Little VGL evaluation rate (mSec)
#define LVGL_EVAL_MSEC      10


// ArduCAM image resolution
//  Undefine for 640x480 resolution, otherwise 320x240
//  Note: CAM_RES_HIGH also sets the jpeg decoder scale factor in render_jpg.c
#define CAM_RES_HIGH

#ifdef CAM_RES_HIGH
#define CAM_SIZE_SPEC       OV2640_640x480
#define CAM_JPEG_WIDTH      640
#else
#define CAM_SIZE_SPEC       OV2640_320x240
#define CAM_JPEG_WIDTH      320
#endif


// ArduCAM max jpg image size (based on CAM_SIZE_SPEC)
#ifdef CAM_RES_HIGH
#define CAM_MAX_JPG_LEN     65536
#else
#define CAM_MAX_JPG_LEN     32768
#endif

// Lepton default gain mode
#define LEP_DEF_GAIN_MODE  LEP_SYS_GAIN_MODE_HIGH

// Combined image (ArduCAM + Lepton + Metadata) json object text size
// Based on the following items:
//   1. Base64 encoded ArduCAM maximum image size: CAM_MAX_JPG_LEN*4 / 3
//   2. Base64 encoded Lepton image size: (160x120x2)*4 / 3
//   3. Metadata text size: 2048
//   4. Json object overhead (child names, formatting characters, NLs): 256
// Manually calculate this and round to 4-byte boundary
#ifdef CAM_RES_HIGH
#define JSON_MAX_IMAGE_TEXT_LEN (1024 * 160)
#else
#define JSON_MAX_IMAGE_TEXT_LEN (1024 * 128)
#endif

// Max command response json object text size
#define JSON_MAX_RSP_TEXT_LEN   1024

// Maximum incoming command json string length (large enough for longest command)
#define JSON_MAX_CMD_TEXT_LEN   256

// Maximum TCP/IP Socket receiver buffer
//  This should be large enough for the maximum number of command received at a time
//  (probably 2 is ok)
#define CMD_MAX_TCP_RX_BUFFER_LEN 1024

// TCP/IP listening port
#define CMD_PORT 5001


// Recording Intervals and names
#define REC_INT_0_VAL  1
#define REC_INT_0_NAME "1 Second"
#define REC_INT_1_VAL  5
#define REC_INT_1_NAME "5 Seconds"
#define REC_INT_2_VAL  30
#define REC_INT_2_NAME "30 Seconds"
#define REC_INT_3_VAL  60
#define REC_INT_3_NAME "1 Minute"
#define REC_INT_4_VAL  300
#define REC_INT_4_NAME "5 Minutes"
#define REC_INT_5_VAL  1800
#define REC_INT_5_NAME "30 Minutes"
#define REC_INT_6_VAL  3600
#define REC_INT_6_NAME "1 Hour"
#define REC_INT_NUM    7





#endif // SYSTEM_CONFIG_H

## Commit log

2020-02-28 Initial checkin
    [display_mount.dxf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]
2020-05-22 Version 2.0 and readme files
    1. Version 2.0 firmware
    a. Support Client WiFi mode - DHCP or Static IP address
    b. Additional camera configuration - Timelapse interval, lepton gain, palettes
    c. New setting screens and other gui changes including additional palettes
    d. New commands to support configuring settings and wifi
    e. Include Lepton telemetry in image files
    f. Bug fixes in the command parser and CCI interface
    2. Version 2.0 application
    a. Support new commands with new controls & layout
    b. Support resizing
    c. Additional palettes
    d. Image streaming mode
    3. Include documenation
    a. Added readme files
    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
    [cci.c, cci.h, gui_screen_main.h]
2022-07-14 Added 3D printed base/display mount
    [bottom_mount.scad, bottom_mount.stl, display_mount.dxf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]

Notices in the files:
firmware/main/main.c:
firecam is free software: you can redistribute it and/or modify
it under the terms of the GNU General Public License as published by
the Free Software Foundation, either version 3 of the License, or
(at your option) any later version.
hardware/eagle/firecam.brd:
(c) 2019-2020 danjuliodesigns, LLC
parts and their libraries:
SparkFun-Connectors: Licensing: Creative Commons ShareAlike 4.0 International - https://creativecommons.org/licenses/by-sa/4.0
